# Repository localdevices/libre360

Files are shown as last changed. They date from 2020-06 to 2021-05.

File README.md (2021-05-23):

# libre360

## Overview

This repository contains code for the EECS 398 group working on the odm360 project with the Cleveland Metroparks, and all the great extensions and reinventions of that code for all the other things we want to do. The idea is to build a 360 camera from individual cameras for the purposes of high quality 3D reconstructions in challenging environments where drones don't work or don't work well.

The original plan used a Sony α6000 using [gphoto2](http://gphoto.org/), but the project has been expanded to use [that fancy new Raspberry Pi camera](https://www.raspberrypi.org/products/raspberry-pi-high-quality-camera/).

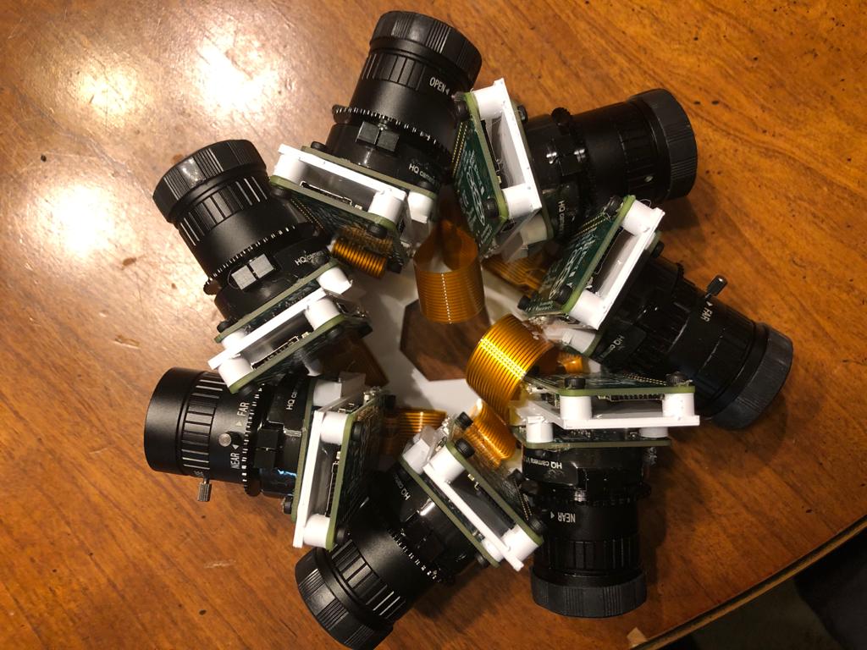
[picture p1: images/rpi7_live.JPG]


See also: https://www.opendronemap.org/2020/05/360-cameras/

## Quickstart: Install from packages

- Buy Pis, SD cards, cameras, wires, GNSS receivers, etc. [Parts list here](provisioning/setup_pi.md).
- Solder, jumper, assemble, etc. [Instructions here](provisioning/setup_pi.md).
- Flash parent SD card with [Raspberry Pi OS](https://www.raspberrypi.org/downloads/raspberry-pi-os/)
- Add empty ```ssh``` file and appropriate ```wpa_supplicant.conf``` [like this](https://www.raspberrypi.org/documentation/configuration/wireless/headless.md) with wifi info to boot partition on that SD card. Put it in the parent Pi and start it up.
- SSH into the pi ```ssh pi@raspberrypi.local``` with password ```raspberry```.
- Change the default password ```passwd```, update, upgrade ```sudo apt update && sudo apt upgrade -y``` and install Git ```sudo apt install git -y```.

#### TODO: correct this
- Add the package repo to ```/etc/apt/sources.list```
- Install using ```dpkg --install odm360.deb```

## Slightly less quick start: Install from scripts

This is a quick listing of install steps, intended for someone who already knows most of what's needed and just needs a checklist/reminder. [Full instructions here](provisioning/setup_pi.md).

- Buy Pis, SD cards, cameras, wires, GNSS receivers, etc. [Parts list here](provisioning/setup_pi.md).
- Solder, jumper, assemble, etc. [Instructions here](provisioning/setup_pi.md).
- Flash parent SD card with [Raspberry Pi OS](https://www.raspberrypi.org/downloads/raspberry-pi-os/)
- Add empty ```ssh``` file and appropriate ```wpa_supplicant.conf``` [like this](https://www.raspberrypi.org/documentation/configuration/wireless/headless.md) with wifi info to boot partition on that SD card. Put it in the parent Pi and start it up.
- SSH into the parent pi ```ssh pi@raspberrypi.local``` with password ```raspberry```.
- Change the default password ```passwd```, update, upgrade ```sudo apt update && sudo apt upgrade -y``` and install Git ```sudo apt install git -y```.
- Clone the odm360 repo ```git clone https://github.com/OpenDroneMap/odm360.git```, cd into the folder ```cd odm360```
- Run ```provisioning/parent_pi_setup.sh```
- Run the web app with ```python3 -m flask run --host=0.0.0.0```
- See the dashboard by going to [http://raspberrypi.local:5000/](http://raspberrypi.local:5000/) in your browser

## LongStart: Install Manually

BLAH BLAH

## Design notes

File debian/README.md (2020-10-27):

# Debian Packaging

ODM360's software consists of a number of utilities that run on a set of Raspberry Pi system-on-a-chip computers, generally one for each camera (the "children") and one controlling the whole rig (the "parent"). To simplify installation, the whole project is provided as a set of [Debian packages](https://en.wikipedia.org/wiki/Deb_(file_format)). These install on [Raspberry Pi OS](https://www.raspberrypi.org/downloads/raspberry-pi-os/) using the standard [dpkg](https://en.wikipedia.org/wiki/Dpkg) utility.

## How the packages are created and served
We use a continuous integration system based on  [github actions](https://docs.github.com/en/free-pro-team@latest/actions).

When a GitHub repo is modifed (such as when someone does a git push), GitHub checks for a file in the directory ```.github/workflows```. In this case, it finds ```.github/workflows/debian.yml``` which is set to execute ```on:push``` (whenever someone pushes). This file contains a workflow called  ```build-packages```, which creates a set of virtual machines on which to build installable packages for the Raspberry Pi's (which use [armhf](https://wiki.debian.org/ArmHardFloatPort) architecture). 

After building the packages, the workflow creates a Git branch of the repository called apt-repo, which contains only a set of packages (it's actually slightly misleading to think of apt-repo as a "normal" branch of the repository, as it contains nothing but the packages; it's simply using Git's branch functionality to create a set of packages based on the latest code in the "real" repository).

The apt-repo branch is then served as a set of package repositories&mdash;they function as a Web endpoint with the structure and function of a Debian repo (one for each branch other than apt-repo itself). These repos can be added to the ```/etc/apt/sources.list``` and installed directly from the Internet onto the Pi's. 

For example, add ```deb [trusted=yes] https://github.com/OpenDroneMap/odm360/blob/apt-repo/ main odm360``` to ```/etc/apt/sources.list```.

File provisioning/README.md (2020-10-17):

# Setup

Normally ODM360 is installed using the Debian packages (see the Readme in the [debian directory](https://github.com/OpenDroneMap/odm360/tree/main/debian) for more details).

This directory contains documentation and working scripts for the manual install process, some of which provides the source material for the .deb package-based install.

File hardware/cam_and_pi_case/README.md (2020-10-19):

# Summary
Inspired by:
https://cad.onshape.com/documents/ca6ab81a1f03d00a92dc3a1a/w/ec248be1a5031c1add481cc3/e/32ebe526ad34a96bca31c931

but refactored to be printed in two parts, and ensure adequate cable clearance when used with standard tripod.

Connect pi0 and high quality pi camera together using this, then bolt into base.

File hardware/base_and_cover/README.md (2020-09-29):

# Summary

This piece is a simple n-sided ring intended for outward facing cameras. The default is 7-sided, but changes may be made to the OpenSCAD parameters to change the number of cams, depending on use case and lens used. 7-cams is based on assumption of using "Official Raspberry Pi HQ Camera Lens - Wide Angle". In theory, one could create a 360 panorama from 6 of these lenses, but in practice, a bit of overlap is more forgiving.

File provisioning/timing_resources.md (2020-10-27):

# Documents and resources for timing

## Building a Network Time Protocol (NTP) server

- [The Wikipedia page for NTP](https://en.m.wikipedia.org/wiki/Network_Time_Protocol) has a lot of good background info.
- Here is [a ridiculously detailed recipe for a stratum 1 NTP server on a Pi](https://www.satsignal.eu/ntp/Raspberry-Pi-NTP.html).
- And a [slightly more lightweight recipe](https://www.satsignal.eu/ntp/Raspberry-Pi-quickstart.html) from the same guy
- Would you have expected Florida Man to be helpful here? Me neither. Nevertheless, the South Florida Amateur Astronomers Association has provided a nice write-up of a [Pi-based, GPS PPS-driven NTP server](https://www.slsmk.com/how-to-setup-a-gps-pps-ntp-time-server-on-raspberry-pi/)
- We could also use an Arduino. Here's [a forum post with some leads on that, plus a downloadable sketch](https://forum.arduino.cc/index.php?topic=197870.0)
- Here's a [recent blog on building a stratum 1 NTP server that doesn't require compiling NTP](https://blog.thelifeofkenneth.com/2020/03/building-raspberry-pi-stratum-1-ntp.html?m=1)
- Here's a guy who's apparently built a [Pi-based base station with a Web interface](https://github.com/Stefal/rtkbase). 

## Testing and syncing
- Here is a [recipe for building a test rig with a millisecond-precise time display](https://www.instructables.com/id/High-speed-Clock-for-Slow-motion-Videos/)

## More bits of GPS info
- [A detailed explanation of NMEA](http://www.gpsinformation.org/dale/nmea.htm)
- [The Wikipedia page on NMEA](https://en.wikipedia.org/wiki/NMEA_0183) is pretty good too.
- More background on [GPSD](https://ozzmaker.com/using-python-with-a-gps-receiver-on-a-raspberry-pi/), which is the easiest way to sync time from the PPS pulse.
- A Python library for [parsing NMEA](https://github.com/Knio/pynmea2); very useful and transparent. I have a high bar for using a library instead of writing my own code to parse this kind of data, but this is definitely worth using.
- Turns out GPSD is terribly complicated. [Here's a FAQ](https://gpsd.gitlab.io/gpsd/faq.html#raspberry) that might help.
- And a great writeup on PPP that includes some discussion of [how to control the ublox from GPSD tools](https://gpsd.gitlab.io/gpsd/ppp-howto.html)
- The [protocol spec for u-blox GNSS devices](https://www.u-blox.com/sites/default/files/products/documents/u-blox6_ReceiverDescrProtSpec_%28GPS.G6-SW-10018%29_Public.pdf), which includes a description of the .ubx binary format on page 85. This includes the _control_ message protocols, which we could eventually use to replace u-center configuration with our own messages.

## Hardware and wiring
- [Good diagrams of Pi Zero pinouts](https://pi4j.com/1.2/pins/model-zero-rev1.html)
- Incredibly annoying how complicated it is just to [enable serial pin communicatcion](https://learn.adafruit.com/raspberry-pi-zero-creation/enable-uart).

## Correction
- [Homemade CORS station](https://community.st.com/s/feed/0D50X0000AIcbSLSQZ)?

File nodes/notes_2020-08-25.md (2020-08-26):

# Configuration
* Primarily via web interface
	* Flask
	* Will work on in next meeting
* Status LED
* Physical Button for starting and stopping capture

RPi 4 will be both Parent and Time Server

# Wiring
* Parent <-> Child coordination stream
* PPS -- one wire pulse from GPS
* GPS Nav information stream (UBLOX)
* (Potential) RTCM
* Raw .UBX for post processing
* Photo streams
	* Pi cams to pi zeros
	* Pooled photos on Pi4 / Webpage
* Power
	* Source
		* USB 
		* LiMetal (12v)
		* 12V->5V converter
	* Pi Zeros
	* Pi4 B
	* GPS
	
Other tasks
Buy $7 LED array
Get large arduino

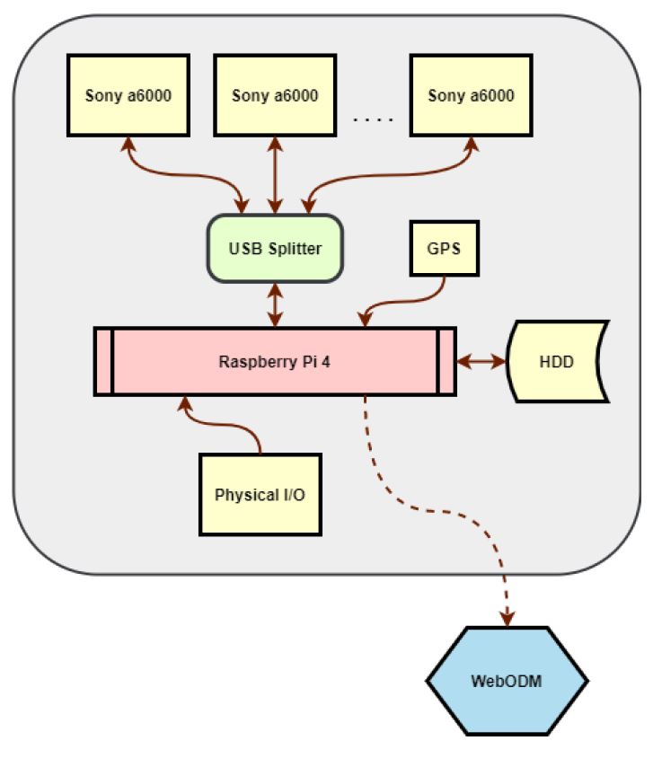
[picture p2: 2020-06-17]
images/overallschematic.JPG

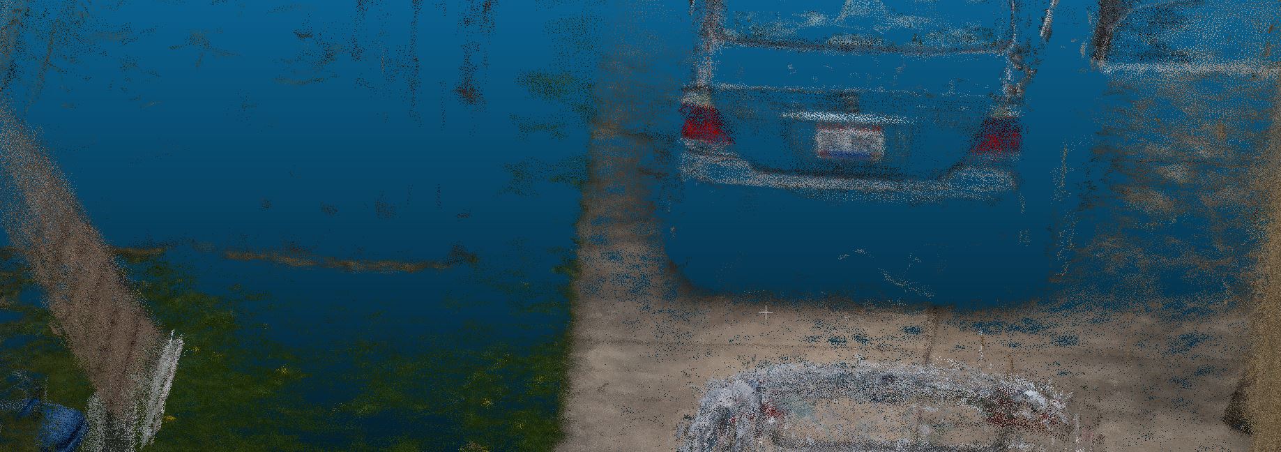
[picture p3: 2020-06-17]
images/points.jpg

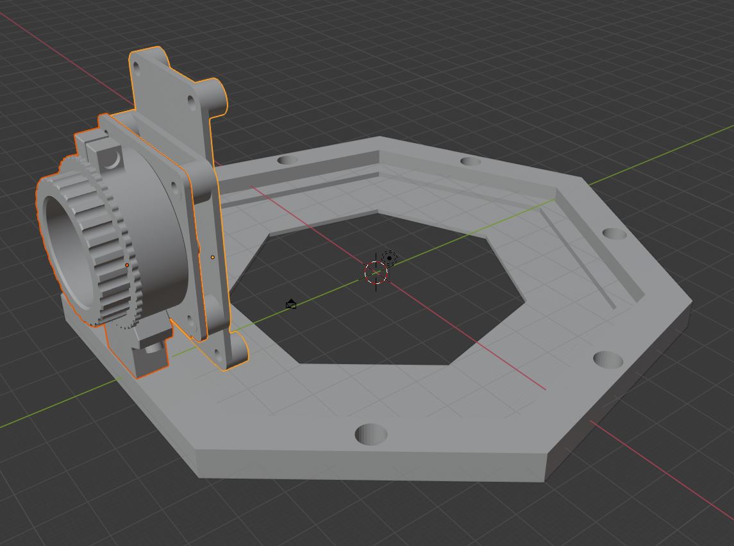
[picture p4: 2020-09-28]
images/rpi7.JPG

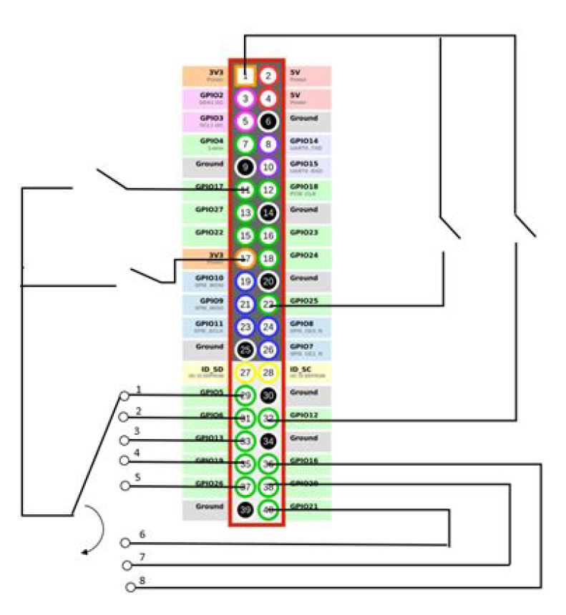
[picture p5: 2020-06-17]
images/gpiolayout.JPG

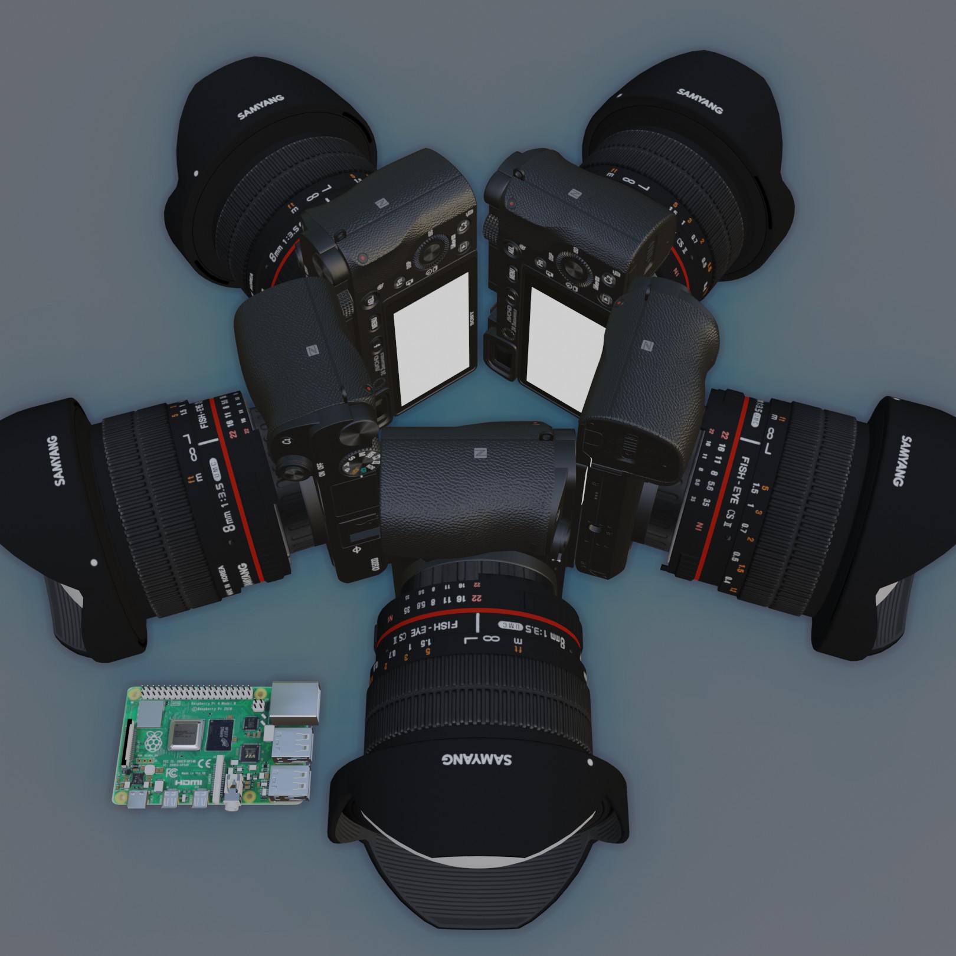
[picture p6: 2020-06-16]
images/cameras5.jpg

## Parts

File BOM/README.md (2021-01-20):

- [ ] [Arducam 120 Degree Ultra Wide Angle CS Lens for Raspberry Pi HQ Camera, 3.2mm Focal Length with Manual Focus](https://www.arducam.com/product/arducam-cs-lens-for-raspberry-pi-hq-camera-120-degree-ultra-wide-angle-cs-mount-lens-3-2mm-focal-length-with-manual-focus-ln051/). Also available on [Amazon](https://www.amazon.com/Arducam-Degree-Raspberry-Camera-Length/dp/B08GLYR572/).
- [ ] 7x [Raspberry Pi 4 High Quality Camera](https://www.microcenter.com/product/621303/raspberry-pi-hq-camera-for-raspberry-pi-4)
- [ ] 7x [Raspberry Pi Zero W](https://www.microcenter.com/product/486575/raspberry-pi-zero-w)
- [ ] 8x [Micro USB Cable Cord - A to Up Angle Micro B](https://www.amazon.com/gp/product/B00EANUQ5M/)
- [ ] Optional if power supply is 6S or larger: [VIFLY ShortSaver V2 Smart Smoke Stopper](https://www.viflydrone.com/smokestopper.html) also available at https://www.amazon.com/gp/product/B088TVVNVM/
- [ ] 2x [Multiport USB power supply, 12V-24V Multi Ports](https://www.amazon.com/Charger-Adapter-Identification-Multi-Protection-Charging/dp/B0779D7DFG/)
- [ ] 7x [Arducam 15 Pin 1.0mm Pitch to 22 Pin 0.5mm Camera Cable for Raspberry Pi Zero Version 1.3](https://www.arducam.com/product/arducam-for-raspberry-pi-zero-camera-cable-3-8cm-ribbon-flex-extension-cable-for-pi-zerow-cb008/)
- [ ] 8x (link is 100 pack) [1/4-20 x 1/2 Inch Button Head Socket Cap Bolts Screws](https://www.amazon.com/gp/product/B07MZQ9F5K/)
- [ ] A pile of [Stainless Steel Countersunk Hex Socket Knurled Bolt M2.5x5mm](https://www.amazon.com/gp/product/B00NQ9JX3W/)
- [ ] 1x [Cudy WU1300S AC 1300Mbps WiFi USB 3.0 Adapter or similar adapter](https://www.amazon.com/gp/product/B084FS7BWF/)
- [ ] 2x [Raspberry Pi 4](https://www.microcenter.com/product/609038/raspberry-pi-4-model-b---4gb-ddr4)
- [ ] 8x MicroSD cards (16GB or larger)

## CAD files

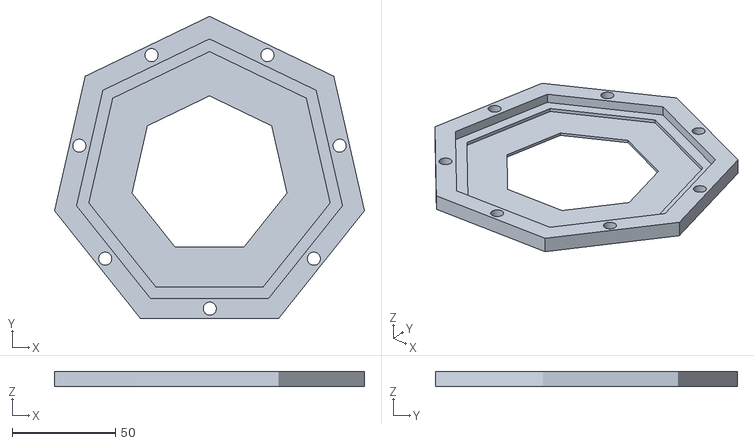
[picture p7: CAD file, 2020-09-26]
hardware/base/7cam.stl
150.2 x 146.5 x 7.50

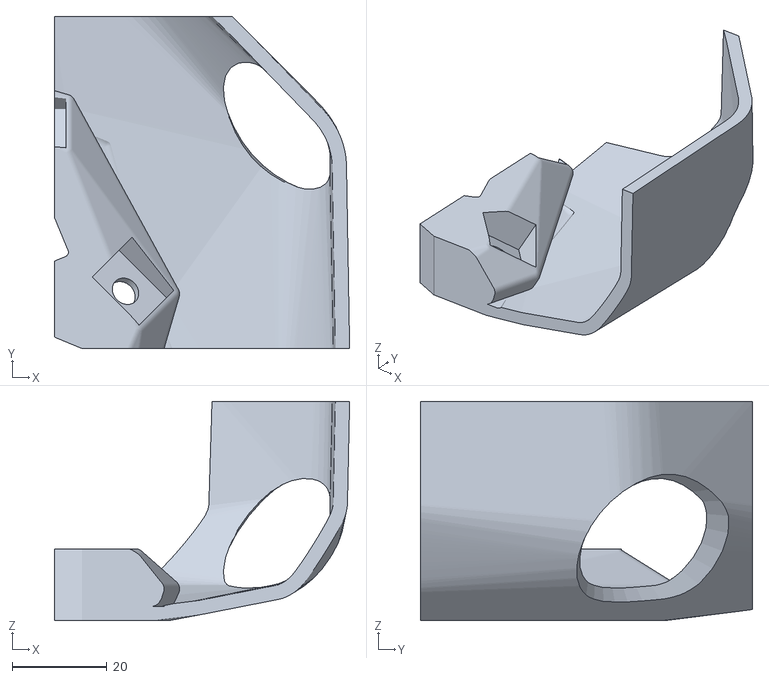
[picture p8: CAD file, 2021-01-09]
hardware/base_and_cover/base_and_cover.stl
62.3 x 70.0 x 46.2

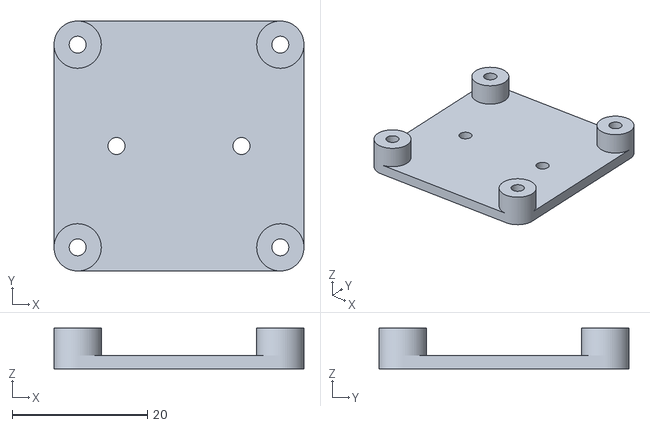
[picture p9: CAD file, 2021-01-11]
hardware/cam_and_pi_case/cam_case.stl
37.0 x 37.0 x 6.00

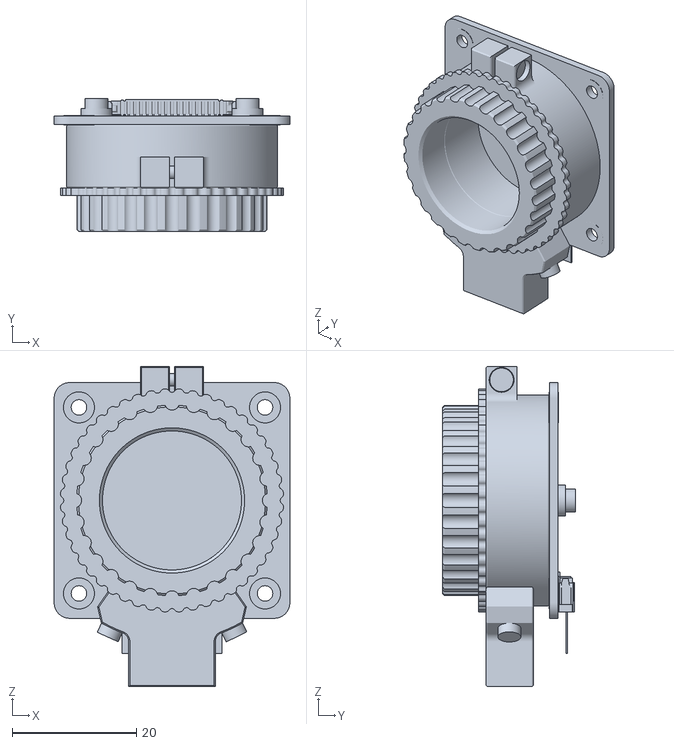
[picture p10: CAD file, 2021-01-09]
hardware/base_and_cover/raspicam.stl
38.0 x 21.4 x 51.6

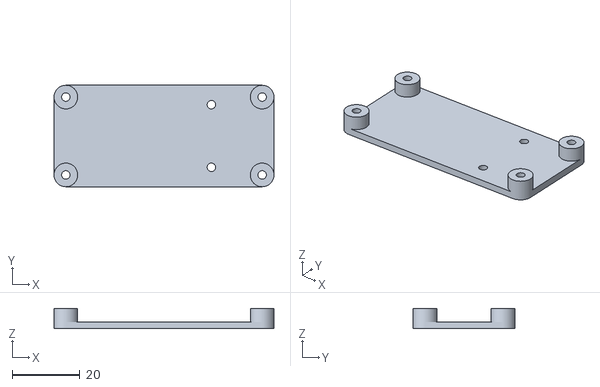
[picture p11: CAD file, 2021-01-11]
hardware/cam_and_pi_case/pi_case.stl
65.0 x 30.0 x 6.00

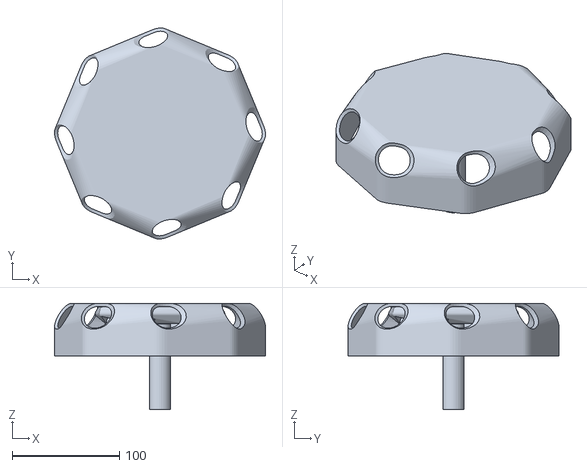
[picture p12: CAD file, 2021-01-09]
hardware/base_and_cover/cover.stl
197.1 x 197.1 x 99.4

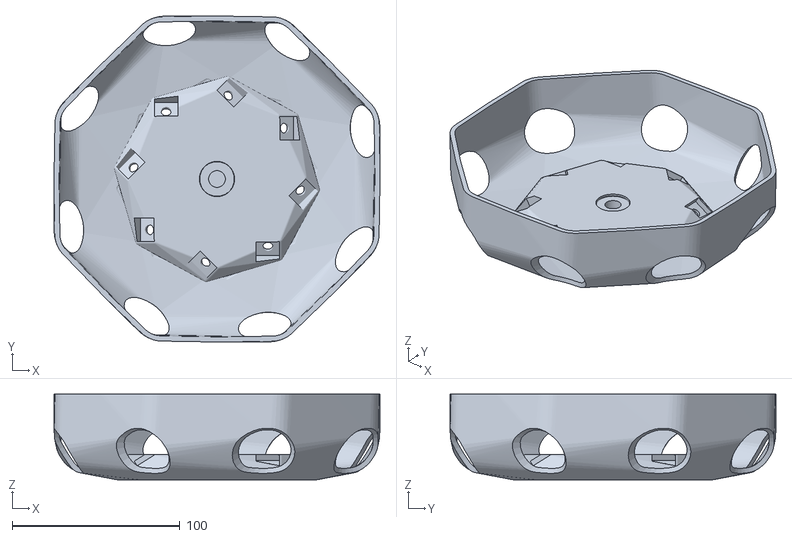
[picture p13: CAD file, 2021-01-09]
hardware/base_and_cover/top_n_cover.stl
194.5 x 194.5 x 51.2

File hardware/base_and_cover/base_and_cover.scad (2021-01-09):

make_odm360("nut");

module make_odm360(type="top"){
    if(type=="top") {
        camera_base_top();
    }
    else if(type=="bottom"){
        camera_base_bottom();
    }
    else if(type=="nut"){
    nut_whole();
    }
}


// Define dimensions. All in mm

num_cams = 8;

edge_thickness = 4; // Thickness of the raised edge where the holes are
edge_width_from_hole = 7; // Width of the edge, material on each side of the hole
hole_diameter = 6; // bolt hole diameter
bolthead_d = 12; // bolt head countersink diameter
bolthead_h = 2; // bolt head height (for countersink depth)
radius_to_hole = 50; // Distance from center to the center of the mounting holes
downangle = 32; // Angle in degrees cameras face downward
cord_hole_length = 20;
cord_hole_width = 10;
cord_hole_offset = 20;

// Alignment indent in edge
// picam base width is 13.5
picam_base_width = 14.1375;
// picam base thickness is 11.5, optimum size is
// 12.1375, but we want to give a little space for
// bad drilling and it's better to index against
// the side
picam_base_thickness = 12.2;
indent_depth = 2;
offset_of_hole = 0; // If the mounting bolt hole isn't centered you can adjust it

// Don't touch
rotate_angle = 360/num_cams;

module picam(){
    translate([14.5,17,8.15]){
        rotate([0, 0, 90 ]){
            import("raspicam.stl", convexity=10);
        }
    }
}

module lenswcone() {
    translate([14.5,17,5.15]){
        rotate([0, 0, 90 ]){
            union(){
                // Lens
                translate([0,0,33]){
                    rotate([90,0,0])
                        {cylinder(r=22.8832/2, h=40);}
                    }

                // Cone of lens view

                translate([0,-22,33]){
                    rotate([90,0,0])
                        {cylinder(r1=0, r2=45.568/2*2, h=19.727*2);}
                    }

                }
            }
        }
}

module lens() {
    translate([14.5,17,5.15]){
        rotate([0, 0, 90 ]){
            union(){
                // Lens
                translate([0,0,33]){
                    rotate([90,0,0])
                        {cylinder(r=22.8832/2, h=36);}
                    }

                }
            }
        }
}

// Holy Cameras Batman
// Camera lens loop
module camera_lenses() {
    for (cam = [1 : num_cams]){
        rotate([0,0,cam * rotate_angle + (360/num_cams)]){
            translate([radius_to_hole, -picam_base_width/2, edge_thickness - indent_depth]){
                rotate([0, downangle, rotate_angle ]){
                    union(){
                        translate([-picam_base_thickness / 2, -picam_base_width / 2, 0]){
                            //picam();
                            lens();
                        }
                    }
                }
            }
        }
    }
}

module picams() {
    for (cam = [1 : num_cams]){
        rotate([0,0,cam * rotate_angle + (360/num_cams)]){
            translate([radius_to_hole, -picam_base_width/2, edge_thickness - indent_depth]){
                rotate([0, downangle, rotate_angle ]){
                    union(){
                        translate([-picam_base_thickness / 2, -picam_base_width / 2, 0]){
                            picam();
                            lens();
                        }
                    }
                }
            }
        }
    }
}


module camera_holeswcone() {
    for (cam = [1 : num_cams]){
        rotate([0,0,cam * rotate_angle + (360/num_cams)]){
            translate([radius_to_hole, -picam_base_width/2, edge_thickness - indent_depth]){
                rotate([0, downangle, rotate_angle ]){
                    union(){
                        translate([-picam_base_thickness / 2, -picam_base_width / 2, 0]){
                            //picam();
                            lenswcone();
                        }
                    }
                }
            }
        }
    }
}

num_sides = 36;
rotate_angle_sides = 360/num_sides;


// Camera Base
module camera_base() {
    mirror([0,1,0]){
        difference(){
            minkowski(){
                hull(){
                    for (cam = [1 : num_cams]){

                        rotate([0,0,cam * rotate_angle + (360/num_cams)]){
                            translate([radius_to_hole, -picam_base_width/2, edge_thickness - indent_depth]){
                                rotate([0, downangle, -rotate_angle]){

                                    translate([-picam_base_thickness / 2, -picam_base_width / 2, 0]){
                                        cube([picam_base_thickness, picam_base_width, indent_depth]);
                                    }

                                }
                            }
                        }
                    }
                }
                sphere(3, $fn=36);
            }
            // Camera mount holes loop
            camera_mount_holes();

        }
    }
}

module camera_mount_holes(){
    for (cam = [1 : num_cams]){

        rotate([0,0,cam * rotate_angle + (360/num_cams)]){
            translate([radius_to_hole, -picam_base_width/2, edge_thickness - indent_depth]){
                rotate([0, downangle, -rotate_angle]){
                    union(){
                        translate([-picam_base_thickness / 2, -picam_base_width / 2, 0]){
                            cube([picam_base_thickness, picam_base_width, indent_depth + 10]);
                        }
                        translate([0, 0, -(bolthead_h * 2 + 10)]){
                            cylinder(r = hole_diameter / 2, h = edge_thickness * 3 + 10, $fn = 64);
                            cylinder(r = bolthead_d / 2 + 0.1, h = bolthead_h + 10, $fn = 64);

                        }
                    }
                }
            }
        }
    }
}

module cord_holes(){
    for (cam = [1 : num_cams]){
        if(cam%2==0) {
            rotate([0,0,cam * rotate_angle + (360/num_cams) * 1.5]){
                translate([cord_hole_offset, 0, -20]){
                        minkowski(){
                            cube([cord_hole_length,cord_hole_width,100]);
                            sphere(1, $fn=16);
                        }
                }
            }
        }
    }
}



module central_post() {

    minkowski(){
        union(){
            cylinder(r1=15, r2=15, h=25, $fn=6);
            cylinder(r1=10, r2=10, h=80, $fn=36);
        }
        sphere(0.5, $fn=16);
    }
    cylinder(r=5, h=90, $fn=36);
}


module camera_hull() {
    hull(){
        camera_lenses();
        camera_base();

        translate([0,0,90]){
            rotate([0,180,45]){
                //mirror([0,1,0]){
                    //union(){
                    camera_base();
                    camera_lenses();
                    //picams();
                    //camera_base();
                    //}
                //}
            }
        }
    }
}

module cover() {
    difference(){
        translate([0,0,90]){
            rotate([0,180,45]){
                difference() {
                    minkowski() {
                        camera_hull();
                        sphere(2, $fn=36);
                    }
                    camera_hull();
                    cube([1000,1000,90],center=true);
                    translate([0,0,90]){
                        rotate([0,180,45]){
                            mirror([0,1,0]){
                                camera_base();
                                mirror([0,1,0]){camera_holeswcone();}
                                //camera_base();
                                //}
                            }
                        }
                    }
                    mirror([0,1,0]){
                        camera_holeswcone();
                    }
                }
            }
        }
        mirror([0,1,0]){camera_mount_holes();}
    }
}


module camera_base_top() {
        mirror([0,1,0]){
            cover();
        }
        rotate([0,180,0]){
            translate([0,0,-90]){
                translate([0,0,90]){
                    rotate([0,180,45]){
                        difference() {
                            mirror([0,1,0]){
                                //union(){
                                camera_base();
                                //camera_lenses();
                                //camera_base();
                                //}
                            }
                            translate([0,0,90-2]){
                                rotate([0,180,0]){
                                    central_post();
                                }
                            }
                        }
                    }
                }
            }
        }
}

module nut_hole(){
    minkowski(){
        translate([0,0,-9]){
            cylinder(r=25.4/2, h=25.4*3/4, $fn=6);
        }
        sphere(1, $fn=16);
    }
}
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

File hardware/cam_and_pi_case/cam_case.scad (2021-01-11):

// Adjustable parameters
length_cam_case = 37;
width_cam_case = 37;
thickness = 2;
screw_hole_radius = 1.25;
screw_hole_offset = 3.5;
pad_height = 6;
nut_diameter = 6;
nut_seat_depth = 4.2;
pad_diameter = 1 + nut_diameter;

// Don't touch
pin = pad_height * 2 + 2;

module cams_corners(pad_height) {
    translate([length_cam_case/2 - 
               screw_hole_offset, width_cam_case/2 - 
               screw_hole_offset,0]) {
                   cylinder(r = pad_diameter/2, 
                            h = pad_height, $fn = 64);
               }
    mirror([1,0,0]) {
        translate([length_cam_case/2 - 
                  screw_hole_offset, width_cam_case/2 - 
                  screw_hole_offset,0]) {
                      cylinder(r = pad_diameter/2, 
                               h = pad_height, $fn = 64);
                  }
              }
                  
    mirror([0,1,0]) {  
        translate([length_cam_case/2 - 
                   screw_hole_offset, width_cam_case/2 - 
                   screw_hole_offset,0]) {
                       cylinder(r = pad_diameter/2, 
                                h = pad_height, $fn = 64);
                   }
               }
    mirror([1,0,0]) {
        mirror([0,1,0]) {    
            translate([length_cam_case/2 - 
                       screw_hole_offset, width_cam_case/2 - 
                       screw_hole_offset,0]) {
                           cylinder(r = pad_diameter/2, 
                                    h = pad_height, $fn = 64);
           }
       }
   }
}
           


// This is not inches. No need to fix.
difference(){
    union() {
        hull(){cams_corners(thickness);}
        cams_corners(pad_height);
    }
    translate([length_cam_case/2 - screw_hole_offset, 
               width_cam_case/2 - screw_hole_offset,-0.1]) {
                   cylinder(r = screw_hole_radius, h = pin, $fn=64);
                   cylinder(r = nut_diameter/2, h = nut_seat_depth, $fn=6);

               }

    mirror([1,0,0]) {    
        translate([length_cam_case/2 - 
        screw_hole_offset, width_cam_case/2 - screw_hole_offset,-0.1]) {
            cylinder(r = screw_hole_radius, 
            h = pin, $fn=64);
            cylinder(r = nut_diameter/2, h = nut_seat_depth, $fn=6);
        }
    }
    
    mirror([0,1,0]) {    
        translate([length_cam_case/2 - 
        screw_hole_offset, width_cam_case/2 - screw_hole_offset,-0.1]) {
            cylinder(r = screw_hole_radius, 
            h = pin, $fn=64);
            cylinder(r = nut_diameter/2, h = nut_seat_depth, $fn=6);
        }
    }

    mirror([1,0,0]) {
        mirror([0,1,0]) {    
            translate([length_cam_case/2 - screw_hole_offset, width_cam_case/2 -  screw_hole_offset,-0.1]) {
                cylinder(r = screw_hole_radius, 
                h = pin, $fn=64);
               cylinder(r = nut_diameter/2, h = nut_seat_depth, $fn=6);
            }
        }
    }
    translate([width_cam_case/4, 0, -0.1]) {
        cylinder(r = screw_hole_radius, h = pin, $fn=64);
    }

    mirror([1,0,0]) {    
        translate([width_cam_case/4, 0, -0.1]) {
            cylinder(r = screw_hole_radius, h = pin, $fn=64);
        }
    }    
}

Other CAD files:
hardware/cam_and_pi_case/pi_case.scad

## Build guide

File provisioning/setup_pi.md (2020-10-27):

# Setting up Raspberry Pi units for use with ODM360

We provide pre-configured images for the various components (Parent, Child, and Timeserver) of the ODM360 kit __(TODO: THAT)__, but for developers or people wishing to customize their setup, this is the full install procedure.

## Buy stuff and get ready
- Get a the appropriate Raspberry Pi for the component you are making.
  - For a TimeServer or a Child, this is a Raspberry Pi Zero W (or the WH, which is the same device but has pre-soldered headers, which will save you some work).
    - Note that the non-W version does not have a WiFi chip, and will be more complicated to set up (it can be done, specifically by sharing network over USB from your computer, but you don't want to).
  - For a Parent, you probably want a heavier Raspberry Pi. __TODO: MENTION WHICH ONE__
- Get a decent quality micro SD card. Absolute minimum 8GB, but wouldn't recommend bigger than 64GB (compatibility issues can come up). Read [this](https://www.raspberrypi.org/documentation/installation/sd-cards.md) or do some research if you want to fiddle with it, otherwise buy a bog-standard brand-name SD card and get on with it. I'm using SanDisk Extreme 64GB cards. They seem fine.
- Work somewhere where there's a WiFi router without any complicated settings. You'll need the SSID and password of the router.
  - If there's a captive portal/login page or other complexities (as in a lot of hotels and some co-working spaces) be warned: your life will suck.
  - If need be (for example if the only WiFi you can find has a captive portal) you can do it all tethered to a WiFi Hotspot from your phone.
- You'll need a computer with an SD card reader.

## Set up base infrastructure on the Pi
- Download the Raspberry Pi OS (32-bit) Lite image from [here](https://www.raspberrypi.org/downloads/raspberry-pi-os/). The Lite image doesn't have a graphical interface (it's "headless") and is therefore smaller to download and will run more efficiently on the limited Pi hardware.
- Unzip the archive and flash the image to your SD card using [Balena Etcher](https://www.balena.io/etcher/). You can mess around with other ways to burn images if you are feeling masochistic; Etcher just works, and it's open source.
- After flashing the image, it's a good idea to eject the card. You'll need to put it back in momentarily, but it seems that sometimes things go wrong if you don't eject and re-insert the card.
- Now you need to get the Pi on the WiFi, enable SSH, and connect to it. The SD card you just flashed should appear in your file explorer, open it up.
  - The SD card should now have two partitions, a small one called ```boot``` and a larger one called ```rootfs``` (if you're on Windows you might not see the ```rootfs``` partition; too bad for you—you should be using Linux anyway—but it doesn't matter for now). Put a ```wpa_supplicant.conf``` file in the ```boot``` partition of the SD card. Explanation of that file [here](https://www.raspberrypi.org/documentation/configuration/wireless/headless.md).

```
ctrl_interface=DIR=/var/run/wpa_supplicant GROUP=netdev
update_config=1
country=TZ

network={
 ssid="OMDTZ-Guest"
 psk="apassword"
}

```

I copy the contents of that example, navigate to the root of the ```boot``` partition on the SD card and type ```nano wpa_supplicant.conf``` and paste in the contents, replacing the SSID, password, and country code with the appropriate ones.
  - Also in the ```boot``` partition, you need to place a file called ```ssh```. It doesn't matter what's in it (an empty file is fine) and there's no extension on the filename. This enables [SSH](https://en.wikipedia.org/wiki/Secure_Shell) on the Pi (disabled by default). You can do this on Linux or Mac by navigating to the root of the ```boot``` partition and typing ```touch ssh```.
- Eject the SD card and remove it from your computer, put it in the Pi, and power it up. Wait about 90 seconds to make sure it has time to boot up before you try to connect to it.
- Make sure your computer is connected to the same WiFi network as the Pi, open a terminal, and type ```ssh pi@raspberrypi.local```.
  - Didn't work? ```Could not resolve hostname...``` or something like it? Sigh. Ok, try to figure out if the Pi is on the WiFi. You can try [nmap](https://nmap.org/) to attempt to identify every device on your local subnet with ```nmap -sP 192.168.X.0/24```, but I recently found a lovely FOSS application called [Angry IP Scanner](https://angryip.org/); it's great. Try it. If you're lucky, you'll see the Pi on the network along with its IP address, and maybe you can ssh into it using the IP address instead of the ```raspberrypi.local``` alias. If not, you'll have to dive into the world of Google, StackExchange, and the Raspberry Pi forums until you get it sorted.
- Log into the Pi using the default password, which is ```raspberry```. Once you're in, immediately type ```passwd``` (_without_ ```sudo```) and—at the prompts—enter first the old and then the new password (twice). Try not to forget the new password.
- Get everything up to date with ```sudo apt update && sudo apt upgrade -y```. This will take a few minutes, more if your Internet connection is slow.

- Fetch and install the ODM360 code

```
git clone https://github.com/OpenDroneMap/odm360
cd odm360
pip3 install -e .
```

## Physical wiring

You will need to connect the serial communication and power pins on the GNSS receiver to the Raspberry Pi Zero (or other Raspberry Pi). Here's an example with an Ardusimple connected to a Zero (note: this cable harness was made with a kit of DuPont connecters and a crimper, which is the way to go if you are doing more than a little of this).

Pi_wiring
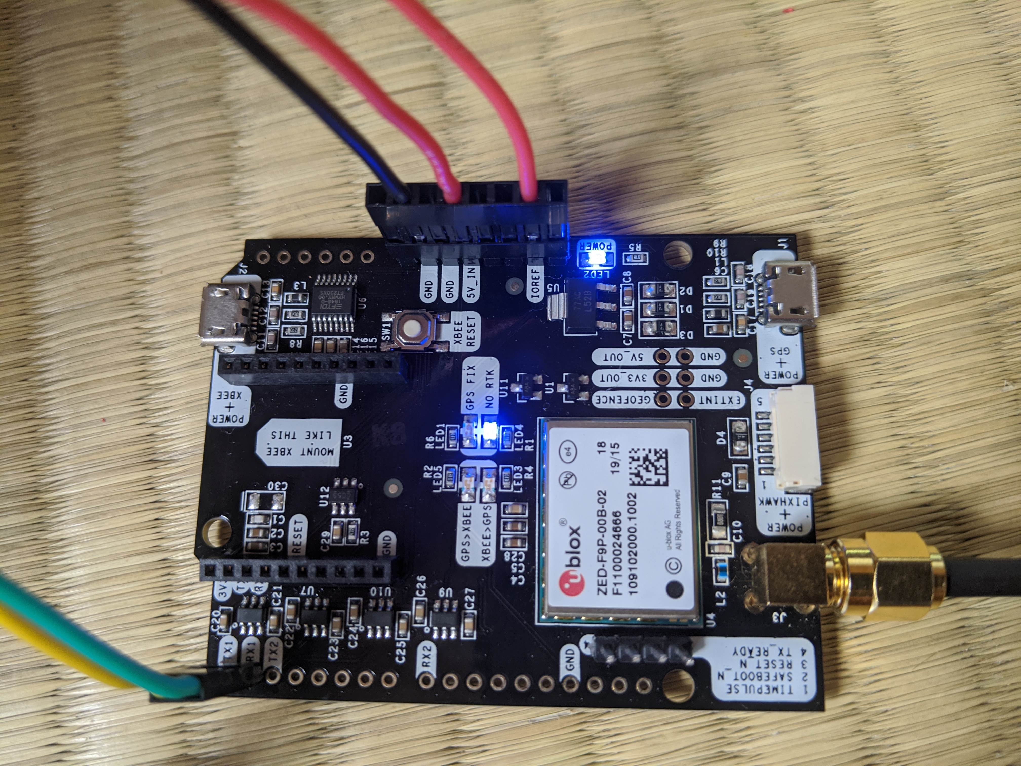
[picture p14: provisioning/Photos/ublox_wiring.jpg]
ublox_wiring

Pi_and_ublox_wiring

*TODO: photo of Ardusimple with header soldered onto PPS pin and connected to an appropriate Pi GPIO pin*

## Setting up NTP for a server and client device on the local network

### On all devices

Raspberry Pi OS comes with a lightweight version of NTP client called systemc-timesyncd. We want the full NTP service. Set it up with ```sudo apt install ntp```.

Then become root ```sudo su -``` (you should now be root, and have a hashmark rather than a dollar sign as your terminal prompt).

Stop the default lightweight NTP service (systemd-timesyncd) and start the full NTP:

```
systemctl stop systemd-timesyncd
systemctl disable systemd-timesyncd
/etc/init.d/ntp stop
/etc/init.d/ntp start
```

Test it with ```ntpq -pn```. You should see an infodump that lists what timeservers are being contacted and which of them is the reference being used, marked with an asterisk (*). It may take a few minutes after starting NTP for the asterisk to appear (it takes a while for NTP to be sure of the timing over a network; there's actually a lot of sophisticated stuff going on under the hood to account for network latency)

The configuration to choose other timeservers (which we'll use on the client Pi's to select the timeserver Pi), you edit ```/etc/ntp.conf```.

Stop being root with ```exit``` (you should now be the pi user again).

### Server-specific setup (to share time with others)

Again you have to log in as the root user with ```sudo su -``` (and ```exit``` when you're done).

Edit the ```/etc/ntp.conf``` file again, adding the lines:
```
restrict 192.168.1.0 mask 255.255.255.0

broadcast 192.168.1.255
broadcast 224.0.1.1
```

### Client-specific setup (assuming you already have a server on the network)

Again you have to log in as the root user with ```sudo su -``` (and ```exit``` when you're done).

You should already have the IP address of the timeserver on your network (if not, you can use the hostname).

Edit the ```/etc/ntp.conf``` file, commenting out the existing servers (which will probably be listed as a pool rather than specific servers). Comment them out, and add a line directing NTP to the server on the network. The relevant section of the ```/etc/ntp.conf``` file should look like this when you're done (of course with the correct IP address at the end):

```
#pool 0.debian.pool.ntp.org iburst
#pool 1.debian.pool.ntp.org iburst
#pool 2.debian.pool.ntp.org iburst
#pool 3.debian.pool.ntp.org iburst 
server 192.168.1.15
```

Test with ```ntpq -p```. It may take a few minutes for the client to sync with the server, but when it does, the results of this command should show an asterisk (*) in front of the line for the timeserver.

## TimeServer (now implemented on the Parent)

The TimeServer is a dedicated Raspberry Pi that listens to the GNSS unit and syncs to the ([extremely precise](https://gssc.esa.int/navipedia/index.php/Precise_Time_Reference)) timing pulse from it and provides timing information via [Network Time Protocol (NTP)](https://en.wikipedia.org/wiki/Network_Time_Protocol) to the rest of the kit.

All devices in the ODM360 kit need to have very precise time, _milliseconds count_. Even moving at a walking speed (around 1.5 m/s), more than a few tens of milliseconds of timing offset will already introduce errors larger than the accuracy of a well-functioning GNSS setup. On a vehicle (car, motorcycle, Bajaj, or drone) which moves faster, this is much worse. We aim for synchronization of less than 5ms. 

To work well, the TimeServer must listen to both the [NMEA stream](https://en.wikipedia.org/wiki/NMEA_0183) coming from the GNSS, which provides timestamps per reading (not particularly accurate, but close enough for setting time to the second) as well as the [Pulse Per Second (PPS)](https://en.wikipedia.org/wiki/Pulse-per-second_signal) signal that is sub-millisecond precise.

Once its own clock is set from the GNSS device (making it a [stratum 1 device](https://en.wikipedia.org/wiki/Network_Time_Protocol#Clock_strata)), it provides an NTP server to the other devices. This ideally requires a short-wire, very low-latency, symmetrical (same signal time both directions) network connection—we're still working on getting this right.

The PPS signal needs to be on a separate pin (__TODO: PICTURES OF THE PIN WIRING__) and for best precision should use an interrupt instead of a loop.

### Steps to configure the Pi Zero as a TimeServer

*Note: Much of this can be done while setting up the base Pi just after flashing. It's separated out here so that it can be scripted and eventually added to a [.deb package](https://en.wikipedia.org/wiki/Deb_(file_format)) specific to the TimeServer setup.*

- Change the name of the Pi to "timeserver" ```sudo hostnamectl set-hostname timeserver``` and inform the Pi of this in the hosts file ```sudo sed -i 's/127.0.0.1\tlocalhost/127.0.0.1\tlocalhost timeserver/g' /etc/hosts```

- Disable IPv6 ```sudo sed -i '$s/$/ ipv6.disable=1/' /boot/cmdline.txt```

- Disable the default serial console to free up UART serial line ```sudo sed -i 's/console=serial0,115200 //g' /boot/cmdline.txt```

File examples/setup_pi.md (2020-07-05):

# Setting up Raspberry Pi units for use with ODM360

We provide pre-configured images for the various components (Parent, Child, and Timeserver) of the ODM360 kit __(TODO: THAT)__, but for developers or people wishing to customize their setup, this is the full install procedure.

### Buy stuff and get ready
- Get a the appropriate Raspberry Pi for the component you are making.
  - For a TimeServer or a Child, this is a Raspberry Pi Zero W (or the WH, which is the same device but has pre-soldered headers, which will save you some work).
    - Note that the non-W version does not have a WiFi chip, and will be more complicated to set up (it can be done, specifically by sharing network over USB from your computer, but you don't want to).
  - For a Parent, you probably want a heavier Raspberry Pi. __TODO: MENTION WHICH ONE__
- Get a decent quality micro SD card. Absolute minimum 8GB, but wouldn't recommend bigger than 64GB (compatibility issues can come up). Read [this](https://www.raspberrypi.org/documentation/installation/sd-cards.md) or do some research if you want to fiddle with it, otherwise buy a bog-standard brand-name SD card and get on with it. I'm using SanDisk Extreme 64GB cards. They seem fine.
- Work somewhere where there's a WiFi router without any complicated settings. You'll need the SSID and password of the router.
  - If there's a captive portal/login page or other complexities (as in a lot of hotels and some co-working spaces) be warned: your life will suck.
  - If need be (for example if the only WiFi you can find has a captive portal) you can do it all tethered to a WiFi Hotspot from your phone.
- You'll need a computer with an SD card reader.

### Set up base infrastructure on the Pi
- Download the Raspberry Pi OS (32-bit) Lite image from [here](https://www.raspberrypi.org/downloads/raspberry-pi-os/). The Lite image doesn't have a graphical interface (it's "headless") and is therefore smaller to download and will run more efficiently on the limited Pi hardware.
- Unzip the archive and flash the image to your SD card using [Balena Etcher](https://www.balena.io/etcher/). You can mess around with other ways to burn images if you are feeling masochistic; Etcher just works, and it's open source.
- Now you need to get the Pi on the WiFi, enable SSH, and connect to it. The SD card you just flashed should appear in your file explorer, open it up.
  - The SD card should now have two partitions, a small one called ```boot``` and a larger one called ```rootfs``` (if you're on Windows you might not see the ```rootfs``` partition; too bad for you—you should be using Linux anyway—but it doesn't matter for now). Put a ```wpa_supplicant.conf``` file in the ```boot``` partition of the SD card. Example of that file [here](https://www.raspberrypi.org/documentation/configuration/wireless/headless.md). I copy the contents of that example, navigate to the root of the ```boot``` partition on the SD card and type ```nano wpa_supplicant.conf``` and paste in the contents, replacing the SSID, password, and country code with the appropriate ones.
  - Also in the ```boot``` partition, you need to place a file called ```ssh```. It doesn't matter what's in it (an empty file is fine) and there's no extension on the filename. This enables [SSH](https://en.wikipedia.org/wiki/Secure_Shell) on the Pi (disabled by default). You can do this on Linux or Mac by navigating to the root of the ```boot``` partition and typing ```touch ssh```.
- Eject the SD card and remove it from your computer, put it in the Pi, and power it up. Wait about 90 seconds to make sure it has time to boot up before you try to connect to it.
- Make sure your computer is connected to the same WiFi network as the Pi, open a terminal, and type ```ssh pi@raspberrypi.local```.
  - Didn't work? ```Could not resolve hostname...``` or something like it? Sigh. Ok, try to figure out if the Pi is on the WiFi. You can try [nmap](https://nmap.org/) to attempt to identify every device on your local subnet, but I recently found a lovely FOSS application called [Angry IP Scanner](https://angryip.org/); it's great. Try it. If you're lucky, you'll see the Pi on the network along with its IP address, and maybe you can ssh into it using the IP address instead of the ```raspberrypi.local``` alias. If not, you'll have to dive into the world of Google, StackExchange, and the Raspberry Pi forums until you get it sorted.
- Log into the Pi using the default password, which is ```raspberry```. Once you're in, immediately type ```passwd``` (_without_ ```sudo```) and—at the prompts—enter first the old and then the new password (twice). Try not to forget the new password.
- Get everything up to date with ```sudo apt update && sudo apt upgrade -y```. This will take a few minutes, more if your Internet connection is slow.
- You might as well install a few more basic infrastructure bits while you're at it:

```
sudo apt install -y git python3-pip libgphoto2-dev libatlas-base-dev gfortran
```
- Fetch and install the ODM360 code

```
https://github.com/OpenDroneMap/odm360
cd odm360
pip3 install -e

```

From here you have a basic Raspberry Pi configuration; you can make it into a Parent, a Child, or a TimeServer with the next steps.

### TimeServer

The TimeServer is a dedicated Raspberry Pi that listens to the GNSS unit and syncs to the ([extremely precise](https://gssc.esa.int/navipedia/index.php/Precise_Time_Reference)) timing pulse from it and provides timing information via [Network Time Protocol (NTP)](https://en.wikipedia.org/wiki/Network_Time_Protocol) to the rest of the kit.

All devices in the ODM360 kit need to have very precise time, _milliseconds count_. Even moving at a walking speed (around 1.5 m/s), more than a few tens of milliseconds of timing offset will already introduce errors larger than the accuracy of a well-functioning GNSS setup. On a vehicle (car, motorcycle, Bajaj, or drone) which moves faster, this is much worse. We aim for synchronization of less than 5ms. 

To work well, the TimeServer must listen to both the [NMEA stream](https://en.wikipedia.org/wiki/NMEA_0183) coming from the GNSS, which provides timestamps per reading (not particularly accurate, but close enough for setting time to the second) as well as the [Pulse Per Second (PPS)](https://en.wikipedia.org/wiki/Pulse-per-second_signal) signal that is sub-millisecond precise.

Once its own clock is set from the GNSS device (making it a [stratum 1 device](https://en.wikipedia.org/wiki/Network_Time_Protocol#Clock_strata)), it provides an NTP server to the other devices. This ideally requires a short-wire, very low-latency, symmetrical (same signal time both directions) network connection—we're still working on getting this right.

The PPS signal needs to be on a separate pin (__TODO: PICTURES OF THE PIN WIRING__) and for best precision should use an interrupt instead of a loop.

#### Steps to configure the Pi Zero as a TimeServer

*Note: Much of this can be done while setting up the base Pi just after flashing. It's separated out here so that it can be scripted and eventually added to a [.deb package](https://en.wikipedia.org/wiki/Deb_(file_format)) specific to the TimeServer setup.*

- Change the name of the Pi to "timeserver" ```sudo hostnamectl set-hostname timeserver``` and inform the Pi of this in the hosts file ```sudo sed -i 's/127.0.0.1\tlocalhost/127.0.0.1\tlocalhost timeserver/g' /etc/hosts```

- Disable IPv6 ```sudo sed -i '$s/$/ ipv6.disable=1/' /boot/cmdline.txt```

- Disable the default serial console to free up UART serial line ```sudo sed -i 's/console=serial0,115200 //g' /boot/cmdline.txt```

- Enable UART to recieve NMEA streams from the GNSS over serial pins ```echo $'\n# Enable UART\nenable_uart=1' | sudo tee -a /boot/config.txt```

- Enable a GPIO pin to receive the PPS signal ```echo dtoverlay=pps-gpio,gpiopin=4 | sudo tee -a /boot/config.txt```

- Install some GNSS libraries ```sudo apt install -y gpsd gpsd-clients python-gps pps-tools```

- Configure GPSD to use the serial port instead of searching for a USB device

```
sudo sed -i 's/USBAUTO="true"/USBAUTO="false"/g' /etc/default/gpsd
sudo sed -i 's:DEVICES="":DEVICES="/dev/ttyS0 /dev/pps0":g' /etc/default/gpsd
sudo sed -i 's:GPSD_OPTIONS="":GPSD_OPTIONS="-n":g' /etc/default/gpsd
```

- Start the GPSD service on boot ```sudo systemctl enable gpsd```

- Create symlinks for GPSD to hook to the device ```echo KERNEL==\"ttyS0\", SUBSYSTEM==\"tty\", DRIVER==\"\", OWNER==\"root\", GROUP==\"tty\", MODE==\"0777\", SYMLINK+=\"gps0\" >> /etc/udev/rules.d/09-pps.rules```

- Enable a GPIO pin to receive the PPS signal
```echo $'\n# Enable GPIO for PPS signal\ndtoverlay=pps-gpio,gpiopin=4' | sudo tee -a /boot/config.txt```

- Set up the pps-gpio module ```echo pps-gpio | sudo tee -a /etc/modules```

- Kick the GPS daemon on startup ```sed -i '$ s/exit 0/gpspipe -r -n 1 \&/g' /etc/rc.local``` and ```echo exit 0 | sudo tee -a /etc/rc.local```

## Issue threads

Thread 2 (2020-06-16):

Make Camera class

hcwinsemius, 2020-06-16:
Make a camera class that holds properties and methods. Some suggestions below

**Properties**
- [x] camera name (str)
- [x] camera ID (int randomized nr)
- [x] port (str)
- [x] root folder (str)
- [x] current photo (filename str or in memory photo object, dependent on gphoto2 lib)
- [x] exif tag (dictionary)

**Methods**
- [x] Open a camera connection (serial, USB)
- [x] Take a photo and place
- [x] Prepare a file name based on root folder, camera ID name and current time
- [x] Read exif tag
- [ ] Write exif tag
- [ ] ... more ...

hcwinsemius, 2020-06-17:
I started working on this. Preparing Camera360 class that inherits from gphoto2.Camera. Camera already holds refs to exif tags and lots of other features we may need.

hcwinsemius, 2020-06-19:
Prepare abstractmethod class and several classes with inheritance for use with
- set of cameras working with gphoto2 attached to one raspi
- set of cameras working through a raspi zero with gphoto2
- set of cameras working through a raspi zero with picamera

All classes should to a user behave exactly the same.

Closed 2020-09-05.

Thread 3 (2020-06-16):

Make Ublox class

hcwinsemius, 2020-06-16:
A Ublox class with properties and methods (parent object Camera??)

**Properties**
- [x] baud_rate (int)
- [x] timeout (int, ms)
- [x] port (str)
- [x] serial (serial connection object, see pySerial)
- [x] data (raw data read line by line from serial)
- [x] text (raw data converted in text)

**Methods**
- [x] find ublox port
- [x] open ublox port serial device
- [x] close serial device
- [x] read line from serial device
- [x] read text from serial device (read lines until text is found)
- [ ] parse text to NMEA
- [ ] ... more ...

hcwinsemius, 2020-06-16:
Started adding functionalities, @ivangayton please suggest additional methods we may need.

Closed 2020-06-29.

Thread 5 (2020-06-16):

Provisioning infrastructure

ivangayton, 2020-06-16:
I don't see where it's noted what distro is being used (I assume Raspbian, but could be something else). It's always nice to explicitly standardize the environment.

I'm a fan of .deb files to do that; this way anyone can start with a given widely-available distro and chuck in a .deb archive to get right up to speed; saves users a lot of downloading if they're in a place with crap internet.

hcwinsemius, 2020-06-16:
I guess Raspbian indeed. I am proposing a miniconda environment to quickly get all libs that you need. See issue #4

Closed 2020-07-08.

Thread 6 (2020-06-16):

Prepare a logger object

hcwinsemius, 2020-06-16:
Logging is needed to ensure we know what was going on, I suggest to prioritize this so that all subsequent code uses that logging object. I have standard code for it.

hcwinsemius, 2020-06-17:
@smathermather I implemented logging, can you review? My proposed way of doing it is to open a logger object in our main function (once we have one), and then bring it up in any children with
```
logging.getLogger(__name__)
```
so that the name of the function can be supplied to the logger object, and all classes, funcs, etc all log to the same file. The way that can be done is now provided in examples/ublox_connect.py

smathermather, 2020-06-17:
Looking good:
```
2020-06-17 14:08:25,771 - odm360 - log - DEBUG - Overwriting log messages in file odm360.log.
2020-06-17 14:08:25,771 - odm360 - ublox_connect - INFO - starting...
2020-06-17 14:08:25,771 - odm360 - ublox_connect - INFO - Starting uBlox instance.
2020-06-17 14:08:25,780 - odm360.ublox - ublox - INFO - Found u-blox GNSS receiver on port /dev/ttyACM0
2020-06-17 14:08:25,780 - odm360 - ublox_connect - INFO - Opening port /dev/ttyACM0 for reading
2020-06-17 14:08:25,783 - odm360.ublox - ublox - INFO - Serial port on /dev/ttyACM0 opened with baud rate 9600
2020-06-17 14:08:25,895 - odm360.ublox - ublox - INFO - Line read from ublox on port /dev/ttyACM0 with baud rate 9600
2020-06-17 14:08:25,895 - odm360.ublox - ublox - INFO - Text read from ublox on port /dev/ttyACM0 with baud rate 9600
2020-06-17 14:08:25,895 - odm360 - ublox_connect - INFO - $GNRMC,,V,,,,,,,,,,N,V*37

2020-06-17 14:08:25,900 - odm360.ublox - ublox - WARNING - Serial connection to /dev/ttyACM0 is closed.
```
Per the other channel, we should be logging which camera we are connected to.  Does gphoto have access to any GUID for the cameras?

hcwinsemius, 2020-06-17:
I haven't investigated gphoto2 that much yet. Regardless we can make separate logging messages for each camera. I'll investigate but likely not before tuesday.

hcwinsemius, 2020-06-17:
I can't find a GUID method after a quick search. But the combination of port and device name should be unique. The only problem I see  is that the ID will change when you take the cameras out and stick them back in. I'll dig a bit more if we can use a hardware signature somehow.

Closed 2020-06-19.

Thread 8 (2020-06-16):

Address image directory structure

smathermather, 2020-06-16:
Current directory structure puts photos in a sequence in directories according to camera:
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

We need an approach which instead treats sequences as projects for upload to WebODM api.

hcwinsemius, 2020-07-12:
@smathermather I am more or less at the stage to think about logical structuring of folders. Can you recommend or giva an example of folder structure that would be most ideal for ODM?

smathermather, 2020-07-13:
The structure is pretty straight forward: each sequence that we want to process together (each logical sequence) needs to be uploaded in one go to a NodeODM instance, per [POST /task/new](https://github.com/OpenDroneMap/NodeODM/blob/master/docs/index.adoc#post-tasknew) proceedure.

I imagine a process similar to the following: person in the field triggers the start of a sequence to be stitched together as a single 3D reconstruction. At the end of that sequence the trigger a button to stop the collection of the sequence. That sequence needs organized in a way where when we trigger upload to NodeODM, it all goes as a single zip file.

The simplest way to organize this is that for each logical sequence, we dump them all in the same directory. Alternatively, we simply track what is all part of one sequence and zip up those images into a single zip when it's time to send them to the Node.

Closed 2020-09-29.

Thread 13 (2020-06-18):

support PiCamera objects (side-by-side with gphoto2 Camera objects)

hcwinsemius, 2020-06-18:
For the raspi cameras, we'll need to either supplement or prepare a similarly functioning class for PiCamera objects see [https://projects.raspberrypi.org/en/projects/getting-started-with-picamera](https://projects.raspberrypi.org/en/projects/getting-started-with-picamera)

smathermather, 2020-06-18:
Yes, and it looks like it uses a dedicated port, so we will likely need more hardware, ala:
* https://www.timpoulsen.com/2018/multiple-cameras-with-a-single-raspberry-pi.html
* https://www.arducam.com/docs/cameras-for-raspberry-pi/multi-camera-adapter-board/introduction/

We might need more than one PI to get up to 5 or 7 cameras.

smathermather, 2020-06-18:
But maybe if we do pi zeros for control and transfer, it won't be too much of an investment. It's not clear that the above links allow the new high quality pi cam.

smathermather, 2020-06-18:
Interesting alternative exist that are slightly more turnkey: https://www.arducam.com/product/b0243-arducam-imx477-hq-camera-6/

smathermather, 2020-06-18:
Plus boards meant for 360:
https://www.robotshop.com/en/arducam-arduino-panorama-360-shield.html

smathermather, 2020-06-18:
Adding these here for posterity:
https://www.arducam.com/raspberry-pi-high-quality-hq-camera-imx477/

smathermather, 2020-06-18:
Via @ivangayton for camera synchronization testing: https://www.instructables.com/id/High-speed-Clock-for-Slow-motion-Videos/

smathermather, 2020-06-21:
Adding this here instead of in a readme:

# Exploring the options for a Raspberry PI alternative setup

The existing ODM 360 leverages the Sony α6000 and gphoto2 for control. This has advantages: the primary being that the α6000 is a very nice camera with excellent available optics, a physical leaf style shutter (ideal for photogrammetry), and a great chipset. The disadvantages are cost, weight, and freedom. By freedom we mean that the camera itself is not free or open source.

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

Using the [Raspberry Pi High Quality Camera](https://www.raspberrypi.org/products/raspberry-pi-high-quality-camera/) may be an affordable alternative that could give good results and be free and open source in it's full implementation, and fully supported until 2027. The chipset and optics are likely to be quite adequate for most purposes, so let's step through the logistics and cost. One caveat is that the Pi High Quality camera is built around a video camera chip, and has an electronic, not physical shutter. This has some real implications for photogrammetry which we won't address here.

* $50 camera
* 7.564 (H) x 5.476 (V) mm
* $25, 6mm lens

Using a [field of view calculator](https://zwww.scantips.com/lights/fieldofview.html), this gives us 49.06° vertical field of view, 64.38° horizontal. To create a 360° array, we would need 6 (H) or 7 (V) cameras mounted, which would total $450-$525, which is approximately the price of a single Sony α6000 without the separate lens the Sony needs. These costs do not yet include the cost of the controlling Raspberry Pi nor GPS.

The Sony α6000 rig is 24.3MP x 5 cameras yield a ~120MP synthetic image. The proposed Raspberry PI High Quality Camera is 12.3MP x 7 cameras yielding ~85MP. For comparison, a GoPro Max is 16.6MP.

smathermather, 2020-06-21:
Added a couple commits to add a Pi camera control:
https://github.com/OpenDroneMap/odm360/commit/f32035d36cae45c60ceb4fce3bf55dc34930026a
https://github.com/OpenDroneMap/odm360/commit/8b2c3dc45e745c31ae123811f38bdee81dfd2f88

Closed 2020-07-07.

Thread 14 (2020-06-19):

Time-stamping photos accurately

ivangayton, 2020-06-19:
As we need a precise camera location, the motion of the camera means we need the timestamps to be fairly accurate. Anything more than a few tens of milliseconds between the GNSS point and the photo timestamp will have a measurable impact on the location accuracy if the camera is mounted on a drone or vehicle, and a hundred milliseconds or so will even impact the accuracy of a camera being carried by a walking user.

Basically whenever a photo gets taken (the physical shutter of the camera opens, or in the case of a Pi camera the sensor performs a readout), we need to correlate that to a time with near-millisecond precision. This means either:

- The cameras need to know the exact time and bake that information into the image files they capture, or
- The controller needs to know exactly when the photos are taken and record the timestamps to correlate to the images later.

In the case of the Sony a6000 camera, we might be able to use the hotshoe to capture the flash sync pulse. In that case, the controller needs to have a fast loop (or interrupt) listening for the sync pulses and logging them for each individual camera (possibly using different GPIO pins for each device).

In the case of the Pi cam, each one will need an individual controller (since the cams don't have onboard storage, and each Pi can probably only read/save the data from one camera). So each "Camera" actually consists of a camera, lens, and an individual Raspberry Pi (probably a Pi Zero to keep costs down, though this necessitates a separate cable as the cable that comes with the camera doesn't fit the Zero). Finally, a "Main" pi (probably a big one, not a Zero) would connect to the GPS, sync itself to GPS time (which is more than adequately precise, particularly if we can use the sync pulse of the GPS instead of the NMEA messages to sync time), and then provide Network Protocol Time (NTP) to the other Pi's, probably via serial.

hcwinsemius, 2020-06-20:
This sounds like a logical way forward. Ideally we test whether time stamping is accurate by pushing a current time to a very high frequency digital time display if anything like that exists so that we can test if the time stamp burned into the exiftag is close enough to the time displayed in ms.

hcwinsemius, 2020-06-20:
Resources to setup a gps ardusimple ntp server on the raspi master

[https://www.ardusimple.com/question/rpi-adapter-information/](url)
 [http://www.unixwiz.net/techtips/raspberry-pi3-gps-time.html](url)

smathermather, 2020-06-21:
Since this isn't a GPS hat we are using, unlike in the linked example, I am laboring under the assumption that we'll be soldering a jumper to number 1:
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

ivangayton, 2020-06-21:
We will. There's a moderate amount of soldering that needs doing anyway, unless you pay extra for pre-soldered header pins from ArduSimple.

hcwinsemius, 2020-06-21:
I have some boards with pre-soldered headers. So ready to try any NTP code once we have any.

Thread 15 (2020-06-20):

Method for killing gphoto2 processes

hcwinsemius, 2020-06-20:
It seems that gphoto2 sometimes doesn't gracefully close. I propose to add a killall (using psutil) to any gphoto2 processes in the CameraRig class in case gphoto2 is used as intermediate between controller and camera device. In case picamera is used this is not relevant.

smathermather, 2020-06-21:
This doesn't surprise me. I note that Gabriel had a process for killing gphoto.

Closed 2020-07-12.

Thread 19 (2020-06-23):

Set up timing tester system

smathermather, 2020-06-23:
Includes building a clock to record

smathermather, 2020-06-30:
https://www.instructables.com/id/High-speed-Clock-for-Slow-motion-Videos/

GabrielMaguire, 2020-09-21:
Timer prototype completed. The Arduino Nano writes the digits sequentially to the display, so the necessary delay in code to capture all 4 digits is a function of the camera’s shutter speed. For my iPhone, a 5ms delay allowed me to clearly capture the display output time.

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

smathermather, 2020-09-21:
w00t!

Ok, so there are a few things we want to test: We want to understand across the pi camera's sensor what the rolling shutter timing (and shape) is. And for a collection of pi cameras, we want to understand how close the firing time is between the cameras. These two will give us a sense of what our error will be.

I will close this issue and open the related one.

Closed 2020-09-21.

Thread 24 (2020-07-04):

Own images

smathermather, 2020-07-04:
This doc is good: https://github.com/OpenDroneMap/odm360/blob/master/examples/setup_pi.md. Working through it at the moment. Ultimately we might want our own images with nominal changes: e.g. setting host names for each of the pi zeros so folks don't have to search their network for headless pi zeros.

hcwinsemius, 2020-07-04:
Agreed. I would opt for the central raspi to be host for the children. If
we make prefab images that should be easy. We can even let a smart phone
login to that for logging msgs to the smartphone.

Op za 4 jul. 2020 22:30 schreef Stephen Mather <notifications@github.com>:

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

smathermather, 2020-07-04:
Love it. Yes, the wifi network should be established by the central raspi. In reality, the child images could be all the same, but the parent raspi could configure and differentiate them.

hcwinsemius, 2020-07-05:
We need to distinguish them indeed. Each cam can get a nr and that can be
used in their resp. logs and name of photo folder.

Op zo 5 jul. 2020 00:31 schreef Stephen Mather <notifications@github.com>:

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

ivangayton, 2020-07-05:
Over the weekend I've been working on provisioning Pi's. Obviously I need to do that to set up the NTP server, but the way I've designed my setup, it starts with a fairly generic image; raspberry Pi OS with basic networking, serial ports enabled, and the dependencies for ODM 360 set up. I'm doing this fairly carefully to ensure a nice, lightweight, robust image.

You'll see a couple of markdown files and a script and the examples directory (Steve, you might be already using it to set up your zeros). Once I get a little further, I'll set up a branch for provisioning, that includes a new directory for all that stuff, and submit it as a pull request.

Therefore it should be possible to Snapchat that image, flash multiple cards exactly the same way, and configure them all with scripts, which can indeed be coordinated by the parent.

Closed 2020-10-13.

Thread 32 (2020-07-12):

Inherit parent class in http server for cross cconnection data exchange

hcwinsemius, 2020-07-12:
We need to ensure instructions to a child can be conditional on states of other children (e.g. we only start capturing when all cameras of rig are present).

See examples on https://stackoverflow.com/questions/21631799/how-can-i-pass-parameters-to-a-requesthandler

hcwinsemius, 2020-07-17:
This issue has been fully resolved. So I am closing it.

Closed 2020-07-17.

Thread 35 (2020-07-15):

PiCamera fails after first capture - debug required

hcwinsemius, 2020-07-15:

hcwinsemius, 2020-07-15:
@smathermather can you try again and then get the pull request finalized? If that's successful, please also remove branch "socket"

Closed 2020-07-16.

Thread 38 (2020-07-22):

Improve workflow for PPP and PPK

ivangayton, 2020-07-22:
We are assuming that we can get accurate positions from the rover GPS, which in offline environments may not be true.

Using an Ardusimple setup with radios, we'll get correction from the base station and reasonable RTK. However, without getting a good initial position for the base station, the accuracy won't be optimal. This requires PPP, which in turn requires at least a few hours of raw GNSS data (in UBX/RINEX format, not NMEA). This is currently done using [this](https://github.com/hcwinsemius/RTK_GNSS/blob/master/Positioning_guideline.md) process, which is fragile and difficult.

If we implement a simple serial reader that logs raw UBX data, and prepare a configuration file for a ZED-F9P that sends the appropriate messages on the UART pins, this will be a lot simpler. Configure the GNSS with a single file, activate a base station with the (very simple) serial UBX logger, come back a few hours later, and upload to NRCAN.

Logging UBX will give us the additional benefit of making PPK possible. If for whatever reason RTK is not possible, the rover attached to the camera ball can log UBX with raw GNSS data, which can be used in RTKLIB to post-process.

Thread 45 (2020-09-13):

3D printable case for camera array

smathermather, 2020-09-13:
We will need a 3D printable case for the camera array. Due to license, we may need to deviate from this, but I will be starting with this case for now just for keeping the cables tidy and start to build up the internal structures for holding the cameras:
https://www.thingiverse.com/thing:4445767

smathermather, 2020-09-13:
I am also using this for mockup purposes: https://www.thingiverse.com/thing:4336659

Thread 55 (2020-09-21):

Test cameras with timing system

smathermather, 2020-09-21:
We want to understand across the pi camera's sensor what the rolling shutter timing (and shape) is. And for a collection of pi cameras, we want to understand how close the firing time is between the cameras. These two will give us a sense of what our error will be.

Timer was set up in #19

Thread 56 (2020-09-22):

add uuid for each device and store in child and parent photos table

hcwinsemius, 2020-09-22:

hcwinsemius, 2020-09-22:
Make the DNS name <UUID>.local

smathermather, 2020-09-22:
Related: https://github.com/OpenDroneMap/odm360/issues/62

Closed 2020-10-07.

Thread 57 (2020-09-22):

Create example foreign table registration example

smathermather, 2020-09-22:
See https://github.com/OpenDroneMap/odm360/pull/50 as starting place.

smathermather, 2020-09-22:
Documentation on Postgres FDW: https://www.postgresql.org/docs/current/postgres-fdw.html

First we need to register the extension to expose the functionality:
`CREATE EXTENSION postgres_fdw;`

Now we can register a foreign table:
```
CREATE SERVER foreign_server
        FOREIGN DATA WRAPPER postgres_fdw
        OPTIONS (host '192.83.123.89', port '5432', dbname 'foreign_db');
```

We can adapt this example:
```
CREATE SERVER child_ip_foreign_server
        FOREIGN DATA WRAPPER postgres_fdw
        OPTIONS (host '<child_pi_hostname>', port '5432', dbname 'child_IP_db'); -- we need to figure out how we are assigning IPs or host names... .
```

smathermather, 2020-09-22:
Finally, we actually create what we wanted in the first place: a foreign table from our foreign server to access locally:

```
CREATE FOREIGN TABLE foreign_table (
        id integer NOT NULL,
        data text
)
        SERVER foreign_server
        OPTIONS (schema_name 'some_schema', table_name 'some_table');
```

Which, customized for us might be:

```
CREATE FOREIGN TABLE foreign_table (
	photoid BIGINT
	,projectid BIGINT
	,survey_run text NOT NULL
	,device text NOT NULL
	,photo_filename text NOT NULL
	,photo BYTEA NOT NULL
	,thumbnail BYTEA
)
        SERVER foreign_server
        OPTIONS (schema_name 'public', table_name 'cameras');
```

hcwinsemius, 2020-10-02:
I checked this out. Am I right that all of this shoukd occur on parent side? I have three questions.

Am I correct that we'll need to make 7 of these servers and tables if we have 7 picams? And give each of these a different name?

How do you then merge these tables together?

And finally: what happens if you shutdown devices? Do you then automatically loose that table?

And maybe more finally. How do you extract files from this (query)?

smathermather, 2020-10-02:
Perfect set of questions:
> Am I correct that we'll need to make 7 of these servers and tables if we have 7 picams? And give each of these a different name?

Correct

> How do you then merge these tables together?
```
CREATE MATERIALIZED VIEW photos
SELECT * FROM foreign_table_name1
    UNION
SELECT * FROM foreign_table_name2
     UNION
SELECT * FROM foreign_table_name3
```

smathermather, 2020-10-10:
Closed with https://github.com/OpenDroneMap/odm360/pull/101

hcwinsemius, 2020-10-10:
@smathermather I have tried the recipe just with postgres as user and within psql interactive prompt. I got to this point:
```
odm360=# CREATE USER MAPPING
    FOR postgres
 SERVER pi1_foreign
OPTIONS (user 'odm360', password 'zanzibar');^C
odm360=# select * from pi1_foreign_table;
ERROR:  could not connect to server "pi1_foreign"
DETAIL:  could not connect to server: Connection refused
	Is the server running on host "192.168.178.1" and accepting
	TCP/IP connections on port 5432?
```
The server is definitely on that ip address and the port seems to be default. I can also see the table with ```\detr```, so not sure why it can't be accessed.

smathermather, 2020-10-11:
Yup. It's running there, but you can't get to it because by default PostgreSQL isn't accessible beyond localhost.
https://blog.bigbinary.com/2016/01/23/configure-postgresql-to-allow-remote-connection.html

smathermather, 2020-10-11:
> The server is definitely on that ip address and the port seems to be default. I can also see the table with `\detr`, so not sure why it can't be accessed.

Fixed here: https://github.com/OpenDroneMap/odm360/pull/107

Closed 2020-11-06.

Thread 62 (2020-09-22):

Naming of Pis

smathermather, 2020-09-22:
As network connected devices that have cards that can be swapped around, we need some approaches WRT naming devices.

Current thinking (if I can remember this morning's call):

1. MicroSD cards will be the root of the pi cameras' identities. In that way, data on the pis will follow the identity
1. DHCP will be used for assigning ips, so the pi identity is the important factor in registering the foreign table in the database
1. ... How are we handling domain names? Are we using `<pi_id>.local`? If so, we need to ensure that we don't create broadcast storms in communications with each of the pis. Otherwise, we need a way to track local DNS entries. We can set up a DNS server, or just track them in `/etc/hosts` on the parent pi.

smathermather, 2020-09-22:
I am wondering if we should just use mDNS: https://en.wikipedia.org/wiki/Multicast_DNS

smathermather, 2020-09-22:
Ok, mDNS is the way to go. It will need added to the deployment scripts:
https://www.howtogeek.com/167190/how-and-why-to-assign-the-.local-domain-to-your-raspberry-pi/

Add `sudo apt-get install avahi-daemon` to the deployment scripts. Add `.local` to the name of the device, and Bob's your uncle.

hcwinsemius, 2020-10-10:
Each device now gets a uuid in database upon provisioning.

smathermather, 2020-10-11:
Ok, but does this get set in the local `/etc/hostname` and I don't think we are yet using mDNS to handle naming across the network.

hcwinsemius, 2020-10-11:
No it doesn't. Maybe I am overlooking something. Why would we need hostname to have a uuid? I am using the uuid to recognize which device is online and which photo belongs to which device. It is stored upon provisioning in the child database and retrieved upon starting the child. So I have a fixed uuid available and don't really see a reason to have a uuid name for the hostname as well.

I am pretty sure I am overlookig something. So what do we need it for?

H

smathermather, 2020-10-11:
We can't and shouldn't rely on IPs for communication. We need host names. There are a lot of mechanisms for choosing hostnames, but one approach would be to use `<uuid>`.local that matches the internal `uuid` and install mDNS. This ensures that if the IP address changes, communications can continue using the name.

hcwinsemius, 2020-10-11:
For http requests it is not a problem if ip addresses change. Also in the
database this is not a problem as the views are generated on the fly when
devices come online. Can you clarify in which operation we still need a
fixed name for communication?

Op zo 11 okt. 2020 16:17 schreef Stephen Mather <notifications@github.com>:

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

smathermather, 2020-10-11:
Database: If a DHCP lease expires while the pi0s are connected, the reference on the parent pi for FDW will become wrong, as it points to an address that has now changed.

smathermather, 2020-10-11:
I've got a branch here to implement (split off your foreign tables branch):
https://github.com/OpenDroneMap/odm360/tree/pi_naming

It just needs me to extract the UUID name and add to hostname, but it's time for a zoom call...

smathermather, 2020-11-12:
I don't think we finished this: the pis have mDNS installed, but they are not getting the correct hostname yet.

smathermather, 2020-11-13:
NM. I found where this is happening. Closing again.

Closed 2020-11-13.

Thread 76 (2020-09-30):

Change primary branch to main

smathermather, 2020-09-30:
Per acknowledged issues with branch naming conventions, we should change the primary branch to `main`. I have done this already, but will wait a few days before removing the `master` branch. They are identical at this time.

ivangayton, 2020-09-30:
Wholeheartedly agree. I have already switched my local tracking to main, and deleted master from my local repos. From where I'm standing, you can remove master anytime you like.

hcwinsemius, 2020-09-30:
I'm on main too. If you want to remove, go ahead.

smathermather, 2020-09-30:
Cool. Removed.

Closed 2020-09-30.

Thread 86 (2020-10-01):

Bring images into database 𝚏̶𝚒̶𝚕̶𝚎̶-̶𝚋̶𝚊̶𝚜̶𝚎̶𝚍̶ ̶𝚟̶𝚒̶𝚊̶ ̶𝚖̶𝚞̶𝚕̶𝚝̶𝚒̶𝚌̶𝚘̶𝚛̶𝚗̶

smathermather, 2020-10-01:
To replicate:

* Do normal setup
* Setup for child pi
* Run child database script
* Then examples/photo_bytes.py

Via @hcwinsemius:
> I nailed it now, to where it goes wrong. If I simply read the byte stream (without writing to database) it works fine! It is storing of the byte stream into the database that makes things awfully slow
> It takes 30 seconds to store one photo of about 5 mb
> Unacceptable!

smathermather, 2020-10-01:
Thoughts on possible fixes:
* Increase shared_buffers. As this is already 128MB, this probably isn't the issue
* Increase work_mem. This is defaulting to 4MB and the images are 5MB, so we are immediately going to disk rather than working in memory as long as performance dictates. Suggest we try changing this to 10MB
* If this doesn't work, something drastic like: File System FDW: https://multicorn.readthedocs.io/en/latest/foreign-data-wrappers/fsfdw.html?

hcwinsemius, 2020-10-02:
I tried to temporarily increase work mem by adding:

```SET work_mem = '24MB';```

at the beginning of the sql command and

```RESET work_mem;```

at the end. To no avail unfortunately.....

smathermather, 2020-10-02:
Leaning toward File System FDW, since writing to the file system is fast. Will work on example shortly.

smathermather, 2020-10-14:
Multicorn gives us issues with the foreign table on the parent. An alternate recipe is to do the following:
* Ensure logging is turned off on the table
    * `ALTER TABLE "photos_child" SET UNLOGGED;`
* Save image to disk in a location readable by postgres
* Load image
     * `insert into ptest(photo) values(pg_read_binary_file('/tmp/atticlight.jpg'));`

We can retrieve a lower resolution version of image if needed, as we will likely resize in OpenDroneMap anyway.

hcwinsemius, 2020-10-16:
We moved to a normal table now. I have also a provisioning for automated hostname renaming using the device uuid. @smathermather I am considering to make a combined view as follows. Please comment:

- when starting delete any existing server and foreign table or view left from a previous session.
- when devices come online, simply collect their uuid in the devices table (this already happens).

- when a user clicks on the files page, a set of filters appears for filtering on project and survey_run. The projects and survey runs available are queried from the 'projects' table  at this stage no foreign table exists and no foreign server exists.

When a user has selected a project and survey (or all surveys belonging to one project) only then are foreign tables built from all available children and queried for filenames. The amount will be quite large so I propose that we show per device how many files are available in a simple table. If there are fewer devices online than there should be given the rig size belonging to the query, then an error will be returned instead.

- if the query was successful the 'download' button becomes active and user can finally download a zipfile with the results.

Please comment!

Closed 2020-11-06.

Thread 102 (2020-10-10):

Enabling WiFi in the rig

smathermather, 2020-10-10:
The parent pi should provide the WiFi for the rig. We need to enable this in the deployment scripts, e.g.:
https://learn.sparkfun.com/tutorials/setting-up-a-raspberry-pi-3-as-an-access-point/all

hcwinsemius, 2020-10-10:
Good catch! We do need the rig to also be able to connect to WiFi networks so that data can be exchanged over wifi. This post might help to list WiFi networks and connect to them.

https://raspberrypi.stackexchange.com/questions/69084/wi-fi-scanning-and-displaying-using-python-run-by-php

smathermather, 2020-10-11:
I'm thinking out loud a bit, but I lean toward having the parent pi be the WiFi hub by default -- or maybe it's a config setting to make it the wifi hub. In this way, we can streamline the child pi connections and ensure connectivity. It also isolates the traffic to just the collection of devices: wifi usage on a network shared by other processes could create bottle necks and timing issue which could affect a cascade of issues.

smathermather, 2020-10-11:
As I am thinking about this further, and in concert with https://github.com/OpenDroneMap/odm360/issues/106, I think we need a separate (USB?) NIC for the parent pi. In that way, the parent can communicate with the child pis on it's own network (built in NIC) and separately be patched into an internet connected WiFi (second NIC). A good USB WiFi connection which maxes out the USB3 connections is ~$15-25 and quite performant.

hcwinsemius, 2020-10-11:
I am not sure if this is needed. Having isolated wifi for parent child comms sounds oerfect to me. And...I am pretty sure that a raspi can make a WiFi and at the same be connected to a second network environment. I am not totally confident about this though.

hcwinsemius, 2020-10-11:
Checking it a bit better: we can just use the ethernet for this purpose for starters. If a user wants a wifi connection then I guess we need a second wifi.

smathermather, 2020-10-11:
I like the idea of having an isolated network and a bit of control over it. I could see a common use case in the field where a second wifi card would be useful for e.g. connecting to a cellular hot spot. But it need not be default, though we should design for it.

Closed 2020-10-16.

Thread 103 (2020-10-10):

Battery solution

hcwinsemius, 2020-10-10:
A battery and connection scheme needs adding to the rig and documented.

smathermather, 2020-10-11:
Amen. Starting with this hub: https://www.amazon.com/gp/product/B0779D7DFG/. More to come.

smathermather, 2020-10-11:
And these are the cables I am starting with: https://www.amazon.com/gp/product/B00ENZDFQ4/

hcwinsemius, 2020-10-11:
We do need a battery solution that is easy to carry around preferrably somewhere hidden in the 3d printed shell. Any clue what would be suitable?

smathermather, 2020-10-11:
Given the weight, I am leaning toward having the power supply inside a backpack separate from the cameras. As far as power, either a lipo or li-metal source would work well.

smathermather, 2020-10-16:
Also gonna put this in the mix. It's an optional component, but should give a little more protection in the case of a short:
https://www.amazon.com/VIFLY-ShortSaver-Electronic-Short-Circuit-Available/dp/B088TVVNVM/

smathermather, 2020-10-16:
This means we probably want ~18-24 volts going in, so we can get the full 44 amps we need out at the 2amp ceiling of this short circuit protection. So a 5s or 6s battery is what we need, though I could use a vote of confidence from @ivangayton:

Amps | Volts | Power
-- | -- | --
2.4 |  5 | 12
2.4 |  5 | 12
1 |  5 | 5
1 |  5 | 5
1 |  5 | 5
1 |  5 | 5
-- | Total Power | 44

Giving us:

Battery Type | Minimum Voltage | Max power draw
-- | -- | --
6S | 22.36V | 1.97664
5S | 18.63V | 2.361782

ivangayton, 2020-10-16:
Hmm, I'm worried about 6S—and even 5S—batteries being a hassle to procure and charge. If we stick to 3S, it's extremely easy to buy them, and in an absolute pinch you can use a motorcycle battery instead (or, if you're in a vehicle, use the onboard battery).

5S and 6S batteries often require more expensive and hard-to-find chargers.

So I'm very hesitant to move to a battery that's more hassle to manage just to accommodate the limit of a $10 circuit protector...

Admittedly, it's nice to have a sweet, fast circuit protector instead of a fuse, but I wouldn't say that's worth the cost of switching away from the 3S battery, which can be drop-in replaced by a huge variety of other things.

ivangayton, 2020-10-16:
As for a sanity check:

[Ardusimple with an xbee power draw](https://www.ardusimple.com/question/amperage-needed/) ~200mA
[Pi zero power draw](https://www.jeffgeerling.com/blogs/jeff-geerling/raspberry-pi-zero-power) ~140mA
[Pi 4B loaded to the nuts power draw](https://www.pidramble.com/wiki/benchmarks/power-consumption) ~1280mA

7 Zeros ~1A
2 4B's ~2.6A
1 ArduSimple 0.2A

so about 3.8A altogether.

Double it for safety (and to account for the power loss in the adapter): 7.6A

At 5V that's about 38W.

38W at 12V = 3.2A

So indeed a 2A circuit protector on a 3S battery is not going to be sufficient (though these calculations include a fair safety margin).

We need 3.5A of protection, either a circuit protector or just a dumb 'ol fuse.

smathermather, 2020-10-16:
I did a similar calculation and came up with very similar numbers. The cameras consume a fair amount of current on their own, so I think the doubling is a necessary thing.

Nice thing is, we can offer options based on availability. I might have a 6s I want to use, but we spec the standard model for 3s.

hcwinsemius, 2020-11-10:
6s for amperage is ready.
- soldering between 6s and usb rig needed, then goog-to-go
- parts list and instructions upcoming

smathermather, 2020-11-11:
Ok, we are good to go for the first round. This won't yet power GPS, but as GPS integration isn't complete, this isn't an issue.
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

I'll also document an alternative build without the VIFLY ShortSaver (Smart Smoke Stopper), using a standard smoke stopper.

@ivangayton, I assume it's a bad idea to Y two 3S's together as an alterative to a 6S?

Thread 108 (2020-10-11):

Alternative camera options

smathermather, 2020-10-11:
In the future, as we think about weight and deployment options, it might be worthwhile to look at alternative camera options, e.g.:
https://www.uctronics.com/camera-modules/camera-for-raspberry-pi/arducam-12mp-imx477-mini-high-quality-camera-module-for-raspberry-pi.html

smathermather, 2020-10-11:
This is the same sensor, but a cell phone lens, which makes for a much smaller and lighter set-up.

hcwinsemius, 2021-01-19:
now under #163, closing this issue

smathermather, 2021-01-20:
Strictly speaking, this was an issue for going smaller and keeping the pi API stuff. This is just a hardware change, no other changes needed to the stack. I will re-open, as it's quite a different issue from #163.

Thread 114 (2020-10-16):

Parent child timeout handling on WiFi disconnections

hcwinsemius, 2020-10-16:
Sometimes WiFi interruptions may occur. At this moment there are some small issues with this both on parent and child side that need fixing.

Parent: when a child disconnects this is observed by the parent. It assumes that after 10sec without a request the child is offline and will then interrupt capturing for all children. However on the status pages the status remains on capturing. This needs to be handled in the device state.

Child. The child assumes a disconnection as soon as one faulty response or no response occurs. This has to be changed into a certain time span e.g. 10 seconds by introducing a state that defines the last moment of succesfull request posting

Child: after a disconnection, the camera object must be gracefully closed otherwise an error will appear when a new camera object is established upon reconnection

hcwinsemius, 2020-10-27:
Alternatives for future:
- ethernet connections (switch to raspi 4 children)
- usb data hub (are also unreliable)
- serial connection (multiplexed)

Closed 2020-11-06.

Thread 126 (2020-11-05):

Bootstrap table pageList items not clickable

hcwinsemius, 2020-11-05:
Bootstrap table in file_page.html does not allow changing the page size through a drop-down button. For some reason pageList doesn't work. Dropdown button is there, but unclickable.

@ivangayton do you have brilliant ideas? Tried all I could think of.

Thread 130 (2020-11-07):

Implement preview stream

hcwinsemius, 2020-11-07:
This requires a couple of things:
- a new task to be emitted to children upon requesting a task with status 'ready'. Task should contain which child is expected to provide a live stream
- task implementation on child side involving setting up a continuous video capture generator that yields frames and emits these to parent continuously.
- a new state (previewing or something like that)
- some front end work for buttons and a logical space in cameras end point where to show the frames
Good resource to re-use is https://blog.miguelgrinberg.com/post/video-streaming-with-flask

hcwinsemius, 2020-11-07:
https://requests.readthedocs.io/en/master/user/advanced/

Check multipart post request for the child-side.

hcwinsemius, 2020-11-10:
Docs on Flask-SocketIO.
https://blog.miguelgrinberg.com/post/easy-websockets-with-flask-and-gevent

hcwinsemius, 2020-11-10:
Try this with a socketIO-client connection

hcwinsemius, 2020-11-10:
https://laptrinhx.com/an-easy-to-set-up-raspberry-pi-webrtc-video-streaming-rover-controlled-with-flask-socketio-1876043872/

hcwinsemius, 2020-11-10:
https://github.com/miguelgrinberg/Flask-SocketIO/issues/778

Examples of socket based streaming.

hcwinsemius, 2020-11-18:
https://wiki.videolan.org/Documentation%3aWebPlugin/

Try this?

hcwinsemius, 2020-11-19:
Here is an example of a rtsp stream setup for the vlc plugin with a raspi camera https://www.instructables.com/IP-Camera-Using-the-Raspberry-Pi-Zero-Home-Surveil/

hcwinsemius, 2020-11-19:
Embed vlc seems outdated. Other option: https://flashphoner.com/embedding-html5-rtsp-player-into-a-web-page/

hcwinsemius, 2020-11-19:
uv4l as an option https://www.highvoltagecode.com/post/webrtc-on-raspberry-pi-live-hd-video-and-audio-streaming

hcwinsemius, 2020-11-20:
https://stackoverflow.com/questions/23011302/best-approach-to-get-rtsp-streaming-into-web-browser-from-ip-camera

Possible direction of solution to transcode on parent side with ffmpeg in javascript

hcwinsemius, 2020-11-22:
Quasi live stream with ffmpeg on server side
https://superuser.com/questions/563591/streaming-mp4-with-ffmpeg

hcwinsemius, 2020-11-23:
Working example of a streaming mp4 is as follows:
- server side. Startup a pipeline that listens to a port (5001) and parses it to ffmpeg to create a local file (check if this can also be stdout) with (!) fragmentation. Fragmentation is important so that the file can be read and parsed in smaller chunks.
```
nc -l 5001 | ffmpeg -re -i - -movflags frag_keyframe+empty_moov -vcodec copy outfile.mp4
```
Start up a nc pipeline to the server that provides a raw h.264 stream
```
raspivid -t 0 -rot 180 -w 1920 -h 1080 -fps 30 -b 2000000 -o - | nc <SERVERIP> 5001
```
Now the outfile.mp4 can simple be inserted into a <video> tag in the html page. Problem still is that the file is interpreted only once at the start, and length and reading chunks not renegotiated. This can be solved by dynamically reading the file.

An example of how to dynamically read a file into a buffer instead of using the file itself is provided here. This is the next step.

https://simpl.info/mse/

hcwinsemius, 2020-11-24:
https://gist.github.com/moeiscool/e2a584cca6f4e3f1691a96b6c56856f9

hcwinsemius, 2020-11-24:
https://www.thewebblinders.in/programming/article/rtsp-streaming-on-a-web-browser-6069 worth a try

hcwinsemius, 2020-11-26:
Done lots of provisioning work to get webrtc running. I have a running server now. Next step to get it performing. Now I receive a frame once in a while probably because some software encoding takes place.

Check this to see if it works better

https://stackoverflow.com/questions/57878764/webrtc-h-264-video-streaming-from-raspberry-pi-only-works-with-pi-camera-not-us

hcwinsemius, 2020-11-26:
Also try this recipe with v4l2 on raspi zero.

Closed 2020-12-03.

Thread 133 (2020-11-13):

Update install and use instructions

smathermather, 2020-11-13:
```
# Parent:

sudo apt update && sudo apt upgrade -y && sudo apt dist-upgrade -y && sudo apt autoremove -y && sudo reboot
sudo apt install git
git clone https://github.com/opendronemap/odm360 --depth 1
cd odm360/
./parent_pi_setup.sh
python3 -m flask run --host=0.0.0.0

```

```
# Child:

sudo apt update && sudo apt upgrade -y && sudo apt autoremove -y && sudo apt dist-upgrade -y && sudo reboot
sudo apt install git
git clone https://github.com/opendronemap/odm360
cd odm360/
provisioning/child_pi_setup.sh
```

Parent is now running:
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

Now, to more fundamental questions: how do I turn the child on?

smathermather, 2020-11-18:
Will update the above shortly, but changed the install process for child pis to simplify:
https://github.com/OpenDroneMap/odm360/pull/145

hcwinsemius, 2020-12-15:
Suggestions ToC:
1) Hardware assemblage (subsections on parts, 3D printing, wiring and putting everything together).
2) Installation (short install for .deb users, longer install for developers)
3) how to use: instructions on front end (subsections general explanation 1) make a new project; 2) change settings; 3) Survey; 4) file management; 5) status)

Chapter 1 is on Steve and Ivan, chapter 2 on Schuyler and Ivan; Chapter 3 on Hessel and Iddy

hcwinsemius, 2021-01-19:
For the instructions of software, have a look at this blog for how to set it up.
https://hackernoon.com/the-four-layers-to-great-documentation-b6bfbf4c0de0

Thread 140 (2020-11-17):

Provisioning scripts don't work with Raspberry Pi Desktop, only lite

smathermather, 2020-11-17:
To replicate: install on Raspberry Pi Desktop. After install and reboot, screen is blank.

It works fine on a Raspberry Pi OS Lite / headless.

I have not yet looked into why this is happening.

hcwinsemius, 2021-01-26:
hi Steve, any news on this? Still relevant or not?

smathermather, 2021-01-26:
It's probably still an issue, but I don't know if we need to track this. I'll close it, and if it becomes an issue for someone, we can reopen and investigate.

Closed 2021-01-26.

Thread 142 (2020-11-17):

Download zip should have name of project or project & survey

smathermather, 2020-11-17:
Currently auto-names odm360.

hcwinsemius, 2021-01-26:
closed with small fix

smathermather, 2021-01-26:
w00t!

Closed 2021-01-26.

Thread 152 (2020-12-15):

Change deployment process to allow for updating of child pi ID

smathermather, 2020-12-15:
Setting up a child pi takes a lot of time. For a 7-8 camera rig, the process might take 4-8 hours, including downloading updates. The process can be particularly slow if run on a pi0, which is the recommended platform.

Child Pi deployment scripts currently generate an identity for they pi and set that to hostname, etc.. This means that simple cloning of the SD isn't enough to speed up the above process. We need to deploy each and every time, which can be 30-60 minutes per pi. For simplicity, the generation of an ID on deployment makes sense, but we should add a script which will regenerate the pi id.

smathermather, 2020-12-15:
`child_pi_setup.sh` calls `provisioning/database_setup_child.sh` for this in the deployment process currently. `provisioning/database_setup_child.sh` runs `provisioning/dbase_child.sql` which does lots of stuff, including setting the UUID and setting the hostname and hosts file using this info:

```
# retrieve the child's uuid and change the hostname of child accordingly
hostname_prefix=`sudo -u postgres psql -d odm360 -t -c "SELECT (device_uuid) FROM device;"`
echo $hostname_prefix | sudo tee /etc/hostname
sudo sed -i "s/raspberrypi/$hostname_prefix/g" /etc/hosts
```

So to run an update, we need to:

1. Query the current hostname prefix
2. Truncate the `device` table
3. Update the `device` table with a new ID
4. Use the new hostname prefix to update `/etc/hostname` and `/etc/hosts`

smathermather, 2020-12-15:
Ok, pull request to patch: https://github.com/OpenDroneMap/odm360/pull/153

hcwinsemius, 2021-01-19:
Suggestion: give the child a unique id once it connects to a parent the first time. In this way we can ensure we can use ready-made images for SD cards instead of a tedious install process requiring logging into pis.

smathermather, 2021-01-20:
I would say this is complete with https://github.com/localdevices/odm360/blob/main/child_pi_setup_rename.sh, but we should open a separate issue for API triggering of changes to child pi.

Closed 2021-01-20.

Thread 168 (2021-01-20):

Change wifi adapter to known functional one(s)

smathermather, 2021-01-20:
e.g. https://www.microcenter.com/product/456262/adafruit-industries-usb-wifi-80211b-g-n-module-with-antenna-for-raspberry-pi

smathermather, 2021-01-20:
Nuts: https://www.amazon.com/gp/product/B07LC4LZB6/

smathermather, 2021-01-20:
Also connectors:
https://www.amazon.com/MCIGICM-Upgrade-Female-Bullet-Connectors/dp/B07Q2SJSZ1/
https://www.amazon.com/gp/product/B07Q2SJSZ1/

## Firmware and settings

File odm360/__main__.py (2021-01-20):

#!/usr/bin/python3
"""
Run odm360 with arguments

arguments:
-p or --parent: run as parent (if not set, run as child)
-d or --destination: provide a path name to
"""
from odm360.log import setuplog, start_logger
import gphoto2 as gp
from optparse import OptionParser


def main():
    parser = create_parser()
    (options, args) = parser.parse_args()
    # start a logger with defined log levels. This may be used in our main call
    logger = start_logger(options.verbose, options.quiet, "odm360-child")

    if options.parent:
        if options.n_cams is None:
            raise OSError(
                "Parent needs a number of cameras, please define with -n or --number"
            )
        camera_list = list(gp.Camera.autodetect())
        kwargs = {
            "n_cams": int(options.n_cams),
            "dt": options.dt,
            "logger": logger,
            "debug": options.debug,
        }
        if len(camera_list) > 0:
            # gphoto2 compatible cameras are found, assume a gphoto2 rig
            from odm360.workflows import parent_gphoto2 as workflow
        else:
            # no gphoto2 compatible cameras found, assume serial or ip connection rig
            if options.serial:
                from odm360.workflows import parent_serial as workflow
            else:
                from odm360.workflows import parent_server as workflow
    else:
        kwargs = {
            "logger": logger,
            "debug": options.debug,
            "host": options.host,
        }
        if options.serial:
            from odm360.workflows import child_serial as workflow
        else:
            from odm360.workflows import child_tcp_ip as workflow

        # you are a child, so act like one!

    workflow(**kwargs)


def create_parser():
    usage = "usage: %prog [options]"
    parser = OptionParser(usage=usage)
    parser.add_option(
        "-q",
        "--quiet",
        dest="quiet",
        default=False,
        action="store_false",
        help="do not print status messages to stdout",
    )
    parser.add_option(
        "-n",
        "--number",
        default=None,
        nargs=1,
        dest="n_cams",
        help="Number of cameras to connect",
    )
    parser.add_option(
        "-v",
        "--verbose",
        dest="verbose",
        default=False,
        action="store_true",
        help="print extra debug status messages to stdout",
    )
    parser.add_option(
        "-p",
        "--parent",
        dest="parent",
        default=False,
        action="store_true",
        help="Start odm360 as parent (default: run as child)",
    )
    parser.add_option(
        "-s",
        "--serial",
        dest="serial",
        default=False,
        action="store_true",
        help="Start odm360 parent as serial connection (default: run with socket TCP connection, only used with parent)",
    )
    parser.add_option(
        "-d",
        "--destination",
        dest="root",
        default=".",
        nargs=1,
        help="Local path for storing photos",
    )
    parser.add_option(
        "-t",
        "--time",
        dest="dt",
        default=5,
        nargs=1,
        help="Number of seconds between each photo",
    )
    parser.add_option(
        "-i",
        "--ip",
        dest="host",
        default=None,
        nargs=1,
        help="Ip address of host (only relevant for tcp ip child). If not given, child will search for it",
    )

    parser.add_option(
        "-x",
        "--debug",
        dest="debug",
        default=False,
        action="store_true",
        help="Use debug mode. In this mode, no actual cameras are used yet, only the data flow is performed",
    )
    return parser


if __name__ == "__main__":
    main()

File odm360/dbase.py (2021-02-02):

# This file contains all database interactions
# to not jeopardize Ivan's health, we use functions rather than classes to approach our database
from odm360 import utils
import json
from datetime import datetime


def _generator(cur, table, uuid, chunksize=1024):
    """
    Generator for streaming photos to zip files
    :param cur: cursor
    :param table: name of (foreign) table to retrieve photos from
    :param uuid: photo_uuid of current photo
    :param chunksize: nr of bytes to return per yield
    :return: chunk of photo
    """
    sql_command = f"SELECT photo from {table} where photo_uuid='{uuid}'"
    cur.execute(sql_command)
    photo = cur.fetchall()
    photo = photo[0][0]
    for n in range(0, len(photo), chunksize):
        chunk = photo[n : n + chunksize]
        yield chunk


def create_foreign_table(cur, host):
    cur.execute("SELECT foreign_server_name FROM information_schema.foreign_servers;")
    nr_of_servers = len(cur.fetchall())

    sql_command = f"""
CREATE SERVER IF NOT EXISTS child_{nr_of_servers}
    FOREIGN DATA WRAPPER postgres_fdw 
    OPTIONS (host '{host}', port '5432', dbname 'odm360');
    """
    cur.execute(sql_command)
    cur.connection.commit()

    sql_command = f"""
CREATE FOREIGN TABLE IF NOT EXISTS child_{nr_of_servers} (
photo_uuid uuid
,project_id BIGINT
,survey_run text NOT NULL
,device_uuid uuid NOT NULL
,device_name text 
,photo_filename text NOT NULL
,ts TIMESTAMP
,photo BYTEA NOT NULL)
SERVER child_{nr_of_servers} OPTIONS (schema_name 'public', table_name 'photos_child');
"""
    cur.execute(sql_command)
    cur.connection.commit()

    sql_command = f"""
CREATE USER MAPPING IF NOT EXISTS FOR odm360 
    SERVER child_{nr_of_servers}
    OPTIONS (user 'odm360', password 'zanzibar');
"""
    cur.execute(sql_command)
    cur.connection.commit()


def delete_project(cur, project_name=None, project_id=None):
    """
    Deletes a indicated project and all relations from database (inc. photos, so be careful with this one!)
    Either a project name, or id has to be provided, both default to None.

    :param cur: cursor
    :param project_name: str - default None - if set then project_name is used to find project to delete
    :param project_id: int - default None - if set, then project_id is used to find project to delete
    :return:
    """
    if (project_name is None) and (project_id is None):
        raise ValueError("provide either a project_name or project_id")
    if not (project_name is None):
        sql_command = f"DELETE FROM projects WHERE project_name='{project_name}';"
    else:
        sql_command = f"DELETE FROM projects WHERE project_id={project_id};"

    cur.execute(sql_command)
    cur.connection.commit()


def delete_server(cur, device_uuid):
    srvoptions = f"host={device_uuid},port=5432,dbname=odm360"
    sql_command = (
        "select srvname from pg_foreign_server WHERE srvoptions='{" + srvoptions + "}'"
    )
    cur.execute(sql_command)
    server_name = cur.fetchone()
    # delete server from database
    cur.execute(f"DROP SERVER IF EXISTS {server_name[0]} CASCADE")
    cur.connection.commit()


def delete_servers(cur):
    """
    Deletes all foreign servers from the connected database, including any connected views

    :param cur: cursor
    :return:
    """

    # find names of all existing servers
    cur.execute("SELECT foreign_server_name FROM information_schema.foreign_servers;")
    server_names = cur.fetchall()

    for server_name in server_names:
        cur.execute(f"DROP SERVER IF EXISTS {server_name[0]} CASCADE")
        cur.connection.commit()


def delete_survey(cur, survey_run=None):
    """
    Deletes a indicated survey_run

    :param cur: cursor
    :param survey_run: str - default None - if set then survey_run is deleted
    :return:
    """
    if survey_run is None:
        raise ValueError("provide a survey_run to delete")
    sql_command = f"DELETE FROM surveys WHERE survey_run='{survey_run}';"
    cur.execute(sql_command)
    cur.connection.commit()


def delete_photos(cur, table, survey_run):
    sql_command = f"DELETE FROM {table} WHERE survey_run='{survey_run}';"
    cur.execute(sql_command)
    cur.connection.commit()


def insert(cur, sql_command):
    """
    Insert a new record using a sql command

    :param cur: cursor
    :param sql_command: command to create record with
    :return:
    """
    # try:
    # cur.connection.rollback()
    cur.execute(sql_command)
    cur.connection.commit()
    # except:
    #     raise IOError(f'Insertion command {sql_command} failed')


def insert_device(cur, device_uuid, device_name, status, req_time):
    """
    insert a new device in table (leave out last_photo since it is not available yet).
    :param cur: cursor
    :param device_uuid: uuid - id of device (auto-generated on child side)
    :param status: int - status of device, each int has a specific meaning
    :return:
    """
    sql_command = f"INSERT INTO devices(device_uuid, device_name, status, req_time) VALUES ('{device_uuid}', '{device_name}', {status}, {req_time});"
    insert(cur, sql_command)


def insert_gps(cur, project_id, survey_run, timestamp, msg):
    sql_command = f"INSERT INTO gps(project_id, survey_run, ts, msg) VALUES ({project_id}, '{survey_run}', '{timestamp}', '{msg}');"
    insert(cur, sql_command)


def insert_survey(cur, project_id, survey_run):
    """
    insert a new device in table (leave out last_photo since it is not available yet).
    :param cur: cursor
    :param device_uuid: uuid - id of device (auto-generated on child side)
    :param status: int - status of device, each int has a specific meaning
    :return:
    """
    sql_command = f"INSERT INTO surveys(project_id, survey_run) VALUES ('{project_id}', '{survey_run}');"
    insert(cur, sql_command)


def insert_photo(
    cur,
    photo_uuid,
    project_id,
    survey_run,
    device_uuid,
    device_name,
    photo_filename,
    timestamp,
    fn,
):
    """
    Insert a photo into the photos table.
    :param cur: cursor
    :param photo_uuid: uuid4 str, uuid of photo
    :param project_id: int, project id
    :param survey_run: string, id of survey within project
    :param device_uuid: uuid, id of device
    :param device_name: str, name of device
    :param photo_filename: str, total file path of photo
    :param timestamp: datetime, time stamp of photo
    :param fn: physical file containing photo (can be temporary)
    :return:
    """
    # occurs when parent-side storage is done, no binary data is stored
    ts = timestamp.strftime("%Y-%m-%d %H:%M:%S.%f")
    sql_command = f"""
    INSERT INTO photos_child
    (
    photo_uuid
    ,project_id
    ,survey_run
    ,device_uuid
    ,device_name
    ,photo_filename
    ,ts
    ,photo
    ) SELECT
    '{photo_uuid}'
    , {project_id}
    , '{survey_run}'
    , '{device_uuid}'
    , '{device_name}'
    , '{photo_filename}'
    , '{ts}'
    , pg_read_binary_file('{fn}')
    ;"""
    insert(cur, sql_command)
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

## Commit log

2020-02-17 Image capture script using gphoto2.
    This python code uses the gphoto2 library to interface with our Sony a6000 camera. This code demonstrates the functionality to trigger the camera image capture and download the image onto the SD of t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
2020-02-26 Added print out of camera capture and download times in seconds.
2020-04-27 Camera scripts to capture and download images in parallel.
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2020-06-21 Made super class for serial connections (simplifies any serial device connector now. Ublox class seriously shortened) #3.
    [serial_device.py, ublox.py]
2020-06-22 fixed bug in __init__.py #3.
    [serial_device.py]
2020-06-23 some rework of serial device methods. Moved find_serial to helper function, can now detect multiple devices. #16
    [serial_device.py, ublox.py, ublox_connect.py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]
2020-06-23 refactored and bug fix of camera objects
    [camera360gphoto.py, take_photo.py]
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2020-06-29 bug fix success method #3
    [camera360pi.py, camera360serial.py]
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2020-07-01 replaced scheduler by a proper RepeatedTimer that fires exactly every x seconds interval #3
    [timer.py, workflows.py]
2020-07-01 parent now waits for children to appear (max 60 seconds), decreased sending and receiving serial timeout interval to ensure camera firing is at an exact time epoch (ms accurate) #3
2020-07-02 set resolution fixed #13
    [camera360pi.py, workflows.py]
2020-07-03 corrected port name in toy serial logger
    [toy_serial_logger.py]
2020-07-03 correct baud rate default toy serial logger
    [toy_serial_logger.py]
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2020-07-05 serial compatibility with rpi3/4 to rpi0 fixed #3
    [camera360serial.py, workflows.py]
2020-07-05 corrected log msg target from logger to self.logger #3
    [camera360serial.py, utils.py]
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2020-07-10 bug fixed on child_tcp_ip and debug mode added #26
    [camera360pi.py, workflows.py]
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2020-07-14 added CameraRig as parent object to server and log level #32 #33
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2020-09-04 double server issue #36
    [workflows.py]
2020-09-08 migrated functionalities to flask, still broken due to CameraRig being an object (instead of a dict) #36
    [camera360pi.py, camera360rig.py, workflows.py]
2020-09-11 work on migrating from a class to loose functions (not working yet) #36
    [camera360rig.py]
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2020-09-16 fix types in cameras
2020-09-17 fix so that photos constrained to FK device ID
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2020-09-26 add base hardware
    [7cam.stl]
2020-09-26 Added a parameterized openscad version of the base
    [base.scad, base.stl]
2020-09-26 cleanup non-scad
    [7cam.stl, base.scad, base.stl]
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2020-09-26 Change measurements to fit need
    [base.scad, base.stl]
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2020-09-29 Create rpi-zero_to_hq-cam_-_mount.stl
    Via: https://www.thingiverse.com/thing:4445767
    [rpi-zero_to_hq-cam_-_mount.stl]
2020-09-29 Move cam into own directory
    [rpi-zero_to_hq-cam_-_mount.stl]
2020-09-29 Add Ender3 V2 version
    [E3V2_rpi-zero_to_hq-cam_-_mount.3mf]
2020-09-30 Add baseconnector
    [NiftyMaker_PiCam_back.stl, NiftyMaker_PiCam_front.stl, baseconnector.stl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]
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2020-09-30 fixed problem with binary stream (hopefully...) #56
    [camera360pi.py, dbase.py]
2020-10-01 Added indent to mounting plate to align camera body
    [base.scad, base.stl]
2020-10-01 Correct measurements on indented base
    [base.scad, base.stl]
2020-10-01 Further base refinements
    This version shrinks the overall size slightly, constrains camera rotation only on the sides, and enlargest the hole diameter so the need to drill out should be minimized or eliminated
    [base.scad, base.stl]
2020-10-02 Add draft camera case replacement
    [cam_case.scad, cam_case.stl]
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2020-10-03 Remove rpi-zero_to_hq-cam model
    To be replaced. Partially replaced already.
    [E3V2_rpi-zero_to_hq-cam_-_mount.3mf, NiftyMaker_PiCam_back.stl, NiftyMaker_PiCam_front.stl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]
2020-10-04 Add index holes, make pi pads taller
    [cam_case.stl, pi_case.scad, pi_case.stl]
2020-10-05 Revise pad heights, cam case widths
    [cam_case.scad, cam_case.stl, pi_case.scad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]
2020-10-05 Nut seats for camera mount
    [cam_case.scad]
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2020-10-07 removed parent_server workflow (replaced by app.py) #63
    [workflows.py]
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2020-10-10 simplified dbase to only essential bits, removed insert_photo as this is now fully file based #86
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2020-10-16 debugged camera capture. Still to do, check that picamera object is gracefully closed and reopened if server connection is lost
2020-10-16 example for approaching different children with views. Parts need to flow into dbase.py #86
2020-10-19 More compact base, experiments in cover, refined pi case
    [base.scad, base.stl, cover.scad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]
2020-10-30 prevent reload of camera object when offline status occurred #114
    [workflows.py]
2020-10-30 parent-side camera state also going to offline if child disappears after 5 secs. #114
2020-11-04 end point for zips working, TODO fix download button, somehow that does not work yet
    [dbase.py]
2020-11-05 fixed zip archive functionality #40
    [dbase.py]
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2020-11-06 bug fixes in dbase funcs, added delete_photos #86
    [dbase.py]
2020-11-06 fixing buttons, now fully dynamic so that even Ivan understands what is going on on the front end. You're welcome! #40 #86
2020-11-17 modified front end structure a bit. Some testing with socketio. Not smooth on smartphone yet. #130
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2020-12-02 added required cameras as cam_summary so that we can trigger certain buttons upon availability
2020-12-02 trying http link (instead of rtsp, not working on android) #130 + small changes in layout
    [camera360pi.py]
2020-12-03 changed rtsp to http (rtsp not working on my android phone!) #130
    [dbase.py]
2020-12-10 bit of tilting
    [base.scad]
2020-12-10 change axis of rotation to match orientation of camera
    [base.scad]
2020-12-10 Added bolt head countersinks and tweaked edge width
    [base.scad]
2020-12-12 tweaks to base measurements
    [base.scad, base.stl]
2020-12-15 moved javascript code to separate file, added survey run button behaviour #129
2020-12-15 survey filter implemented, deletion done repeatedly until no files found #129 #128
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2020-12-30 create cover
    [cover.scad]
2020-12-30 add cam for measurements
    [raspicam.stl]
2020-12-30 Internal structure refinement, addition of cover skeleton
    [cover.scad]
2020-12-30 Update cover.scad
    Round the edges a bit, clean up extra code
    [cover.scad]
2020-12-31 Integrate cover and base
    [cover.scad]
2020-12-31 Upper cover mucking about
    [cover.scad]
2020-12-31 update cover
    [cover.scad]
2020-12-31 remove stringer
    [cover.scad]
2020-12-31 clean up unused variables
    [cover.scad]
2020-12-31 begin final modularization
    [cover.scad]
2020-12-31 Base nearly complete
    Still needs nut to connect to pole
    [cover.scad]
2020-12-31 Add nut, smooth pole, etc.
    [cover.scad]
2021-01-01 Expand nut hole and cable holes
    [cover.scad]
2021-01-01 Small adjustment
    [cover.scad]
2021-01-01 Flip case, tweak nut
    [cover.scad]
2021-01-02 camera base top
    [cover.scad]
2021-01-02 Reorg to match new build process
    [base.scad, base.stl, baseconnector.stl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]
2021-01-02 file rename and refactor cam_case
    Rounded edges!
    [base_and_cover.scad, cam_case.scad]
2021-01-02 Refactor pi case
    rounded corners!
    [pi_case.scad]
2021-01-02 Translate cameras to proper position
    Will need to set this as a variable
    [base_and_cover.stl, base_and_cover_even.scad]
2021-01-03 Eased down facet counts to speed openscad rendering
    [base_and_cover.scad]
2021-01-03 Updates and cleanup
    [base_and_cover.scad, base_and_cover.stl, base_and_cover_even.scad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]
2021-01-04 bug in capture ts - timestamp #105
    [camera360pi.py]
2021-01-07 add simple call function at top
    [base_and_cover.scad]
2021-01-08 update to include nut blanks
    [base_and_cover.scad]
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2021-01-09 add nut holes, remove nuts from alignment pins
    [cam_case.scad, pi_case.scad]
2021-01-09 fixed bugs related to timestamps not available in foreign table #105
    [dbase.py]
2021-01-11 add nut seats to cam and pi cases
    [cam_case.scad, cam_case.stl, pi_case.scad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]
2021-01-11 a little smaller
    [cam_case.scad, cam_case.stl, pi_case.scad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]
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2021-01-13 fixed bug in returning None for positions #105
    [dbase.py]
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2021-02-02 attempt to splitting the routes into separate files. Not working yet in case the database is needed. If we import the files in app.py like ```from routes.settings import *```, then the methods stop r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
